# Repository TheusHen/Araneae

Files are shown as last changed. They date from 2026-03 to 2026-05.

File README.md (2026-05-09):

<table align="center">
<tr>
<td>

<h1>Araneae</h1>

</td>
<td>



</td>
</tr>
</table>

<h3 align="center">
Your network should answer to you, not report on you.
</h3>

<p align="center">
  
  
</p>

<p align="center">
  
</p>

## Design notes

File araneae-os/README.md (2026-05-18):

# Araneae OS Starter Kit

Custom OpenWrt image scaffold for a Raspberry Pi Compute Module 4 / Raspberry Pi 4 router appliance with:

- LuCI + HTTPS
- WireGuard VPN generated on first boot
- Mattermost local chat server reachable only from WireGuard
- Docker + Docker Compose
- NVMe/USB/storage packages
- Samba/NFS packages
- collectd monitoring + LuCI statistics
- safe first-boot provisioning scripts

This repo is a starter kit, not a finished commercial firmware. It is designed to get your first Araneae OS image building quickly, then let you evolve it into a full OpenWrt fork later.

---

## Target

Default target profile:

```text
OpenWrt: 24.10.6
Target: bcm27xx/bcm2711
Profile: rpi-4
Package manager: opkg
Hardware: Raspberry Pi CM4 / Raspberry Pi 4 class boards
Rootfs partition: 1024 MB
```

Why 24.10.x? Your current flow uses `opkg`. OpenWrt 25.x/snapshot branches may use different packaging behavior, so keep a separate branch when migrating.

The image uses a larger rootfs partition than OpenWrt's small default because LuCI, Docker, storage packages, and Mattermost support do not fit reliably in the default Raspberry Pi image size.

---

## Build

On Linux or WSL Ubuntu:

```bash
sudo apt update
sudo apt install -y build-essential curl file gawk gettext git libncurses-dev libssl-dev python3 rsync unzip wget zstd

cd araneae-os-starter
./scripts/build-imagebuilder.sh profiles/rpi4-cm4.env
```

The resulting images are copied to:

```text
dist/
```

Flash the appropriate `.img.gz` to SD/eMMC/NVMe using Balena Etcher, Raspberry Pi Imager, or `dd`.

---

## First boot behavior

On first boot, Araneae OS will:

1. Set hostname to `araneae`.
2. Set LAN IP to `192.168.8.1`.
3. Generate WireGuard server keys.
4. Create interface `wg0` at `10.66.66.1/24`.
5. Open UDP `51820` from WAN for WireGuard.
6. Bind Mattermost only to `10.66.66.1:8065`.
7. Block Mattermost access from WAN and LAN.
8. Start Docker and deploy Mattermost + PostgreSQL.

Mattermost Docker images are pulled on first boot. That means the router needs working internet once for the first deployment, unless you later add offline Docker image preloading.

---

## Access

After flashing:

```text
LuCI: https://192.168.8.1
SSH:  ssh root@192.168.8.1
```

Check status:

```sh
/etc/araneae/scripts/status.sh
```

Create a WireGuard peer:

```sh
/etc/araneae/scripts/create-wg-peer.sh phone 10.66.66.2 YOUR_PUBLIC_IP_OR_DDNS
```

Then copy the generated config from:

```text
/etc/araneae/wireguard/peer-phone.conf
```

After connecting to the VPN, open:

```text
http://10.66.66.1:8065
```

---

## Mattermost security model

Mattermost is not exposed on WAN. It is published only on the WireGuard server IP:

```yaml
ports:
  - "10.66.66.1:8065:8065"
```

Firewall rules also block direct LAN/WAN access to port `8065`.

For production, add:

- HTTPS reverse proxy inside the VPN
- pinned Mattermost version updates
- backups for `/srv/araneae/mattermost/volumes`
- external SMTP if you need email invites/password reset
- a private DNS name, for example `chat.araneae.lan`

---

## NVMe behavior

This starter kit is safe by default: it does **not** automatically wipe or format NVMe drives.

If `/dev/nvme0n1p1` already has a filesystem, it tries to mount it at:

```text
/srv
```

If you intentionally want first boot to format `/dev/nvme0n1`, create this marker before building the image:

```text
files/etc/araneae/allow-auto-format-nvme
```

Only do that on blank/test devices.

---

## KSZ9893 / KSZ9896 note

The KSZ switch layer is not fully solved by packages alone. For real hardware you will likely need:

- correct device tree / DT overlay
- DSA configuration, not old `swconfig`, on modern OpenWrt
- the correct Microchip KSZ driver for your kernel/target
- board-specific RGMII/RMII/SPI/I2C reset and interrupt lines

Use Image Builder for the first Araneae OS prototype. Use full OpenWrt buildroot when adding the final KSZ9893 hardware layer.

---

## Repo layout

```text
araneae-os-starter/
├── files/                         # Firmware overlay copied into the image
│   └── etc/
│       ├── araneae/               # Araneae scripts + Mattermost compose
│       ├── init.d/                # araneae-mattermost init service
│       ├── sysctl.d/              # sysctl hardening
│       └── uci-defaults/          # first boot provisioning
├── packages/                      # package lists
├── profiles/                      # target build envs
├── scripts/                       # build scripts
└── docs/                          # notes
```

---

## Next steps for a real Araneae OS

1. Add your CM4 carrier board DTS/DTBO.
2. Confirm KSZ9893 driver path and port naming.
3. Add `luci-app-araneae` for your own dashboard.
4. Add backup/restore for WireGuard peers and Mattermost volumes.
5. Add signed OTA sysupgrade metadata.
6. Add GitHub Actions build pipeline.
7. Split editions: `home`, `travel`, `enterprise`, `dev`.

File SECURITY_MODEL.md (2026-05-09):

# Security model — Araneae

This document describes **assets**, **adversaries**, **trust boundaries**, and **assumptions** for the **Araneae** project, aligned with the principle that your network should answer to you, not report on you, and with the planned technical design (CM4, network, NAS/SSD, LiFePO4 UPS, Rust/C/Assembly, future OpenWrt base).

It is not a substitute for formal analysis for commercial certifications; it guides design, contribution review, and communication with users.

## Security objectives

| Objective | Meaning in Araneae |
|---|---|
| **Confidentiality** | User traffic and data must not be exposed by hidden telemetry, undocumented services, or a default configuration that is “too open.” |
| **Integrity** | Firmware, configuration, and system images must be buildable and verifiable; updates must be understandable to the operator. |
| **Availability** | Internal UPS (LiFePO4, power path, BMS) and sound power practices aim for continuity; the device is still not immune to physical failure or DoS. |

## Primary assets

1. **Data at rest** — content on SSD/NAS (PCIe), possibly user-encrypted (not mandatory for the project, but relevant to threats).
2. **Data in transit** — WAN/LAN, VPN, Tor, proxy; keys and policies defined by the user.
3. **Credentials and policies** — SSH is allowed by philosophy of direct control; that requires **documented hardening** and secure defaults where possible.
4. **Firmware / OS integrity** — OpenWrt or equivalent image, boot chain, possible signatures (future).
5. **Hardware** — CM4, BCM54210PE PHY, KSZ9893 switch, MP1584 converters, UPS chain, USB-C/A, HDMI, **EXT_GPIO** on the 26-pin header.

- **Inside the box:** everything running on the SoC and services chosen by the user is “trusted” only insofar as the **operator** trusts the image they installed and the configuration.
- **Outside the box:** WAN and clients are untrusted by default.

## Adversaries considered

1. **Remote (network)** — exploitation of exposed services, drive-by on the LAN, WAN MITM if the user does not use adequate protections.
2. **Local (internal network)** — compromised LAN devices trying to escalate or reach NAS/services.
3. **Physical, brief access** — USB media insertion, connection to a debug header (SWD), attempts to read storage.
4. **Physical, prolonged possession** — SSD extraction, PCB tampering; mitigation is usually **encryption** + operational policy, not firmware alone.
5. **Supply chain** — components, toolchain, chip firmware blobs (PHY, switch, etc.). The project seeks **maximum openness**, but some elements may remain proprietary in practice; that must be **documented honestly**.

## Privacy and telemetry

- **Product requirement:** **zero undocumented telemetry.** Any diagnostic channel must be **explicit**, **local**, or **opt-in**.
- **Security implication:** no “phone home” reduces surface and metadata leakage, but **does not** remove other vectors (e.g. a misconfigured self-hosted service).

## Hardware — security implications

| Component | Security / trust note |
|---|---|
| **CM4 + eMMC/SD** | Boot vector; protect updates and, if desired, secure boot (future policy to document). |
| **PCIe SSD** | Sensitive data; user encryption recommended for physical threat. |
| **USB-C / USB-A** | Classic attack surface; ESD and mount/automount policy should be conservative by default. |
| **Exposed GPIO / I2C** | Headers improve hackability; they also widen surface if an attacker has physical access. |
| **UPS / I2C (e.g. LTC4015)** | **Local** battery telemetry is desirable for operation; it must not become network exfiltration without consent. |
| **KSZ9893 / MDIO-SPI** | Traffic monitoring is a **feature**; it must be under operator control, not hidden third parties. |

## Software — stack and surface

- **Rust** — services and control (incl. GPIO); reduces some memory-error classes, but logic can still fail.
- **C / Assembly** — low-level integration; careful review; avoid unnecessary `unsafe` in Rust wrapping FFI.
- **OpenWrt (planned)** — defaults, packages, and init must respect Araneae philosophy; contributions that add analytics or undocumented services are **misaligned**.

## What Araneae does not guarantee

- Protection against an **operator** who disables the firewall or exposes insecure services.
- Resistance to **lab-grade physical attacks** without extra measures (mesh, tamper evidence, encryption).
- Security of **third-party applications** (self-hosted — e.g. RustDesk, VPN) beyond what the project documents as integration.

## Relationship to [SECURITY.md](./SECURITY.md)

Vulnerabilities that break the promises above (e.g. hidden telemetry, backdoor, RCE in documented default configuration) should be reported through the security policy. Improvements to this model are welcome via contributions that stay clear and honest about limitations.

## Summary

Araneae combines **verifiable open hardware**, **auditable software**, and **privacy by design**. Effective security depends on **conscious configuration**, **updates**, and — when physical threat matters — **encryption and operational policies** chosen by the user.

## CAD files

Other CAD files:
hardware/Araneae/3d/TLV809K33DBZR.step
hardware/Araneae/3d/USB2514B_M2.step
hardware/Araneae/3d/TMP117AIDRVR.step
hardware/Araneae/3d/RT9742GGJ5.step
hardware/Araneae/3d/LTC4015EUHF.step
hardware/Araneae/3d/MDT320M01001.step
hardware/Araneae/3d/MP1584EN-LF-Z.step
hardware/Araneae/3d/IRLR7843.step
hardware/Araneae/3d/TLV809I50DBZT.step
hardware/Araneae/3d/1048.step
hardware/Araneae/3d/FH12-22S-0.5SH.stp
hardware/Araneae/3d/KSZ9893RNXI.step
hardware/Araneae/3d/NC7SB3157P6X.step
hardware/Araneae/3d/TPS3430WDRCR.step
hardware/Araneae/3d/DF40HC_3.0_-100DS-0.4V_58.step
hardware/Araneae/3d/TPS54331DG4.step
hardware/Araneae/3d/TPS22946YZPR.step
hardware/Araneae/3d/BQ24610RGET.step
hardware/Araneae/3d/ISL94202IRTZ.step

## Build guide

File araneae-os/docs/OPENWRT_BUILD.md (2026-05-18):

# Full OpenWrt buildroot path

Use Image Builder for package + overlay images.

Use full OpenWrt buildroot when you need:

- kernel config changes
- custom DTS/DTBO for your CM4 carrier board
- KSZ9893/KSZ9896 switch integration
- custom LuCI app package
- Araneae branding in base-files
- signed package feeds

Suggested flow:

```bash
git clone https://git.openwrt.org/openwrt/openwrt.git
cd openwrt
git checkout v24.10.6
./scripts/feeds update -a
./scripts/feeds install -a
make menuconfig
```

Then copy `files/` from this starter kit into the OpenWrt tree root and add your board patches.

Build:

```bash
make -j$(nproc)
```

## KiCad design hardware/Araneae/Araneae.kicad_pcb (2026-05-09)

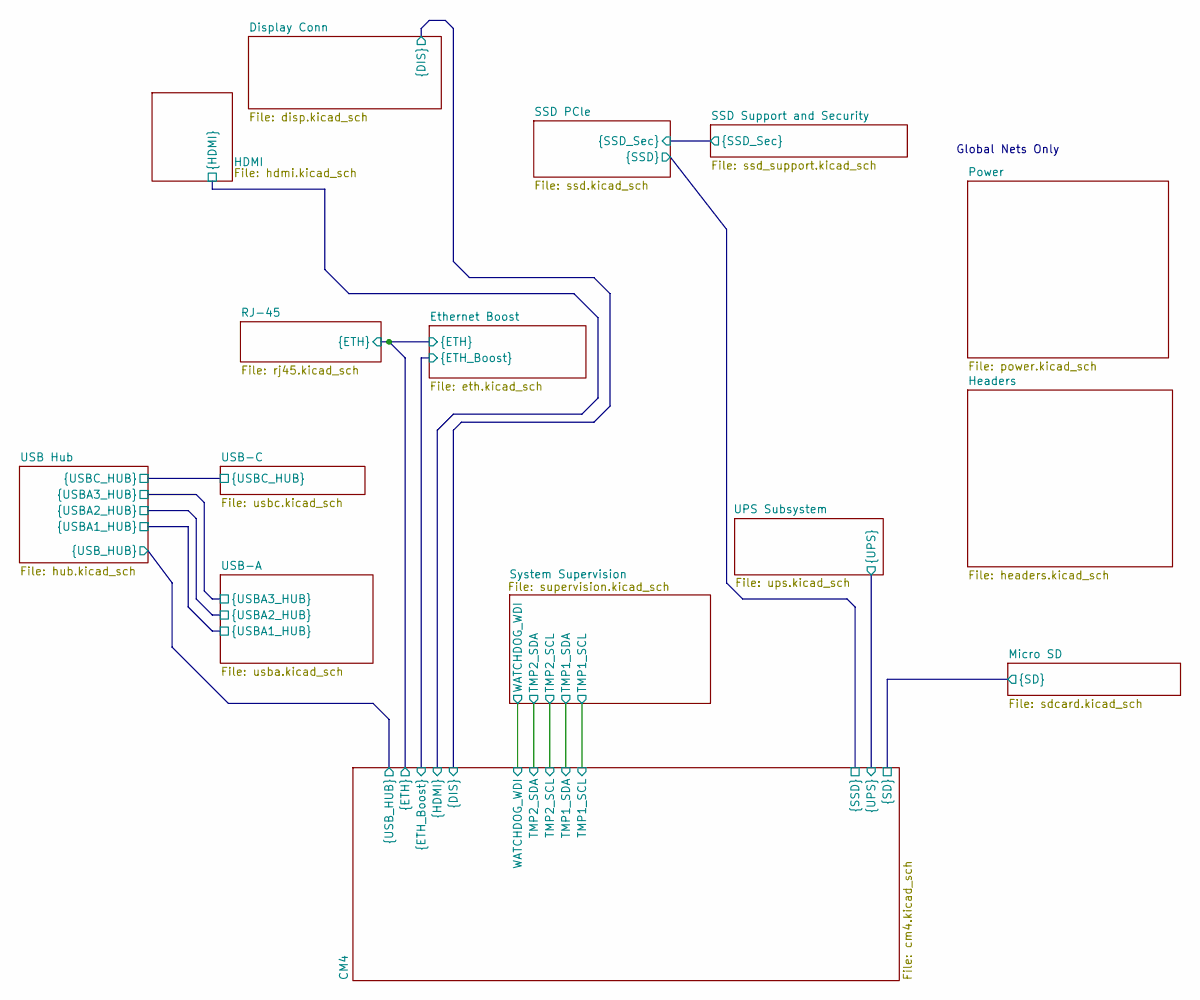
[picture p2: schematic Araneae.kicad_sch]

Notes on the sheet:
Global Nets Only

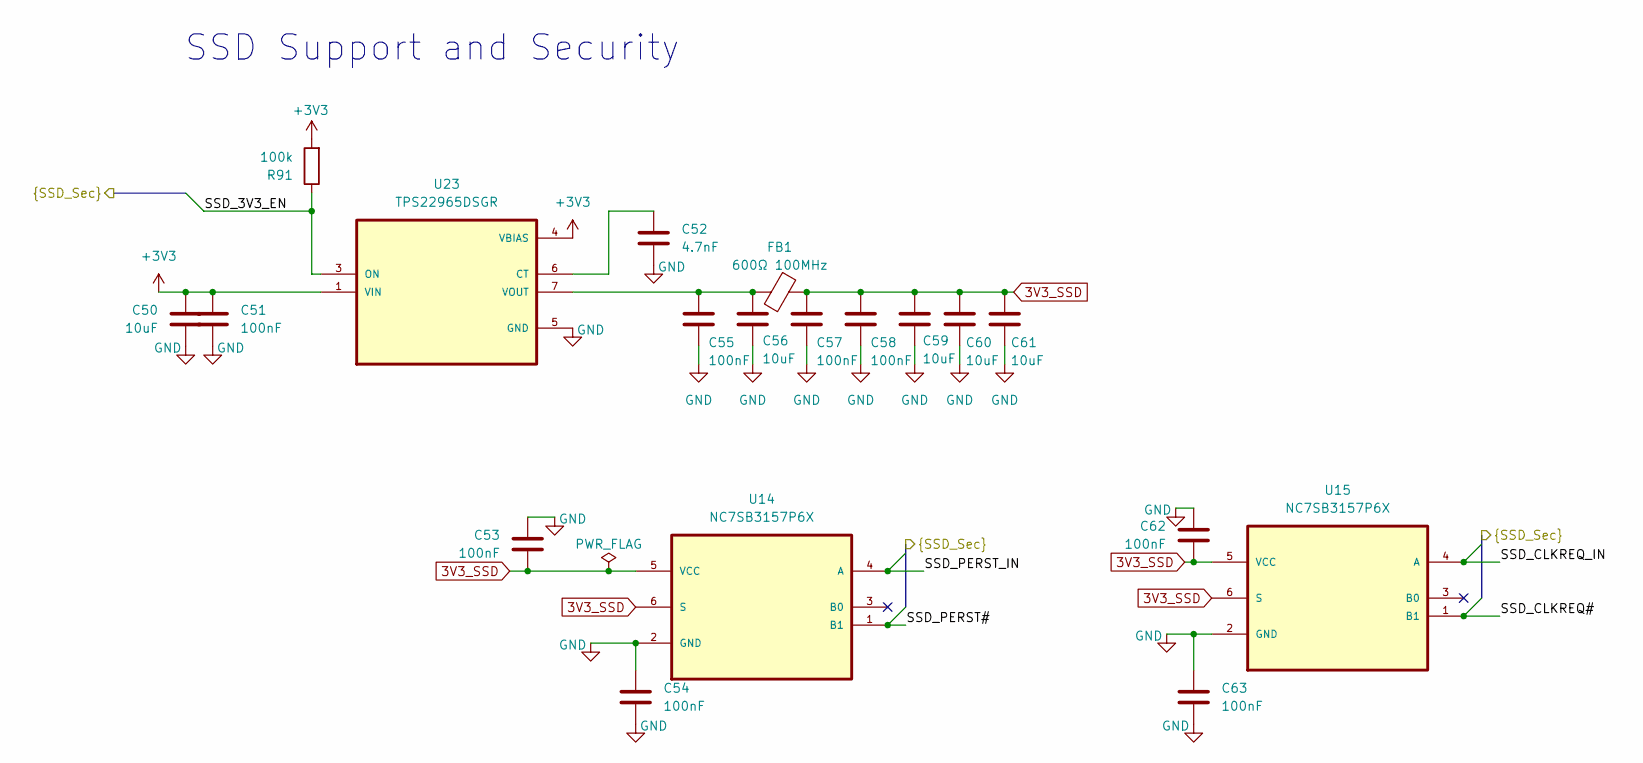
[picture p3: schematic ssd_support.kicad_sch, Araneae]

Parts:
C50, C56, C59: 10uF; C_0603_1608Metric
C51, C57, C62: 100nF; C_0805_2012Metric
C52: 4.7nF; C_0603_1608Metric
C53, C54, C55, C58, C63: 100nF; C_0603_1608Metric
C60, C61: 10uF; C_0805_2012Metric
FB1: 600Ω 100MHz; L_0805_2012Metric
R91: 100k; R_0603_1608Metric
U14, U15: NC7SB3157P6X; SOT65P210X110-6N; MPN NC7SB3157P6X
U23: TPS22965DSGR; SON50P200X200X80-9N

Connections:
3V3_SSD: C53.2, C57.1, C58.1, C59.1, C60.1, C61.1, C62.2, FB1.1, U14.5 (VCC), U14.6 (S), U15.5 (VCC), U15.6 (S); also elsewhere on the board
+3V3: C50.1, C51.1, R91.2, U23.1 (VIN), U23.2 (VIN), U23.4 (VBIAS); also elsewhere on the board
/SSD PCle/SSD_3V3_EN: R91.1, U23.3 (ON)
/SSD PCle/SSD_CLKREQ#: U15.1 (B1); also elsewhere on the board
/SSD PCle/SSD_CLKREQ_IN: U15.4 (A)
/SSD PCle/SSD_PERST#: U14.1 (B1); also elsewhere on the board
/SSD PCle/SSD_PERST_IN: U14.4 (A)
GND: C50.2, C51.2, C52.2, C53.1, C54.1, C54.2, C55.2, C56.2, C57.2, C58.2, C59.2, C60.2, C61.2, C62.1, C63.1, C63.2, U14.2 (GND), U15.2 (GND), U23.5 (GND), U23.9 (GND), U23.9_1 (GND), U23.9_2 (GND); also elsewhere on the board
unnamed: C55.1, C56.1, FB1.2, U23.7 (VOUT), U23.8 (VOUT)
unnamed: C52.1, U23.6 (CT)

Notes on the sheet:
SSD Support and Security

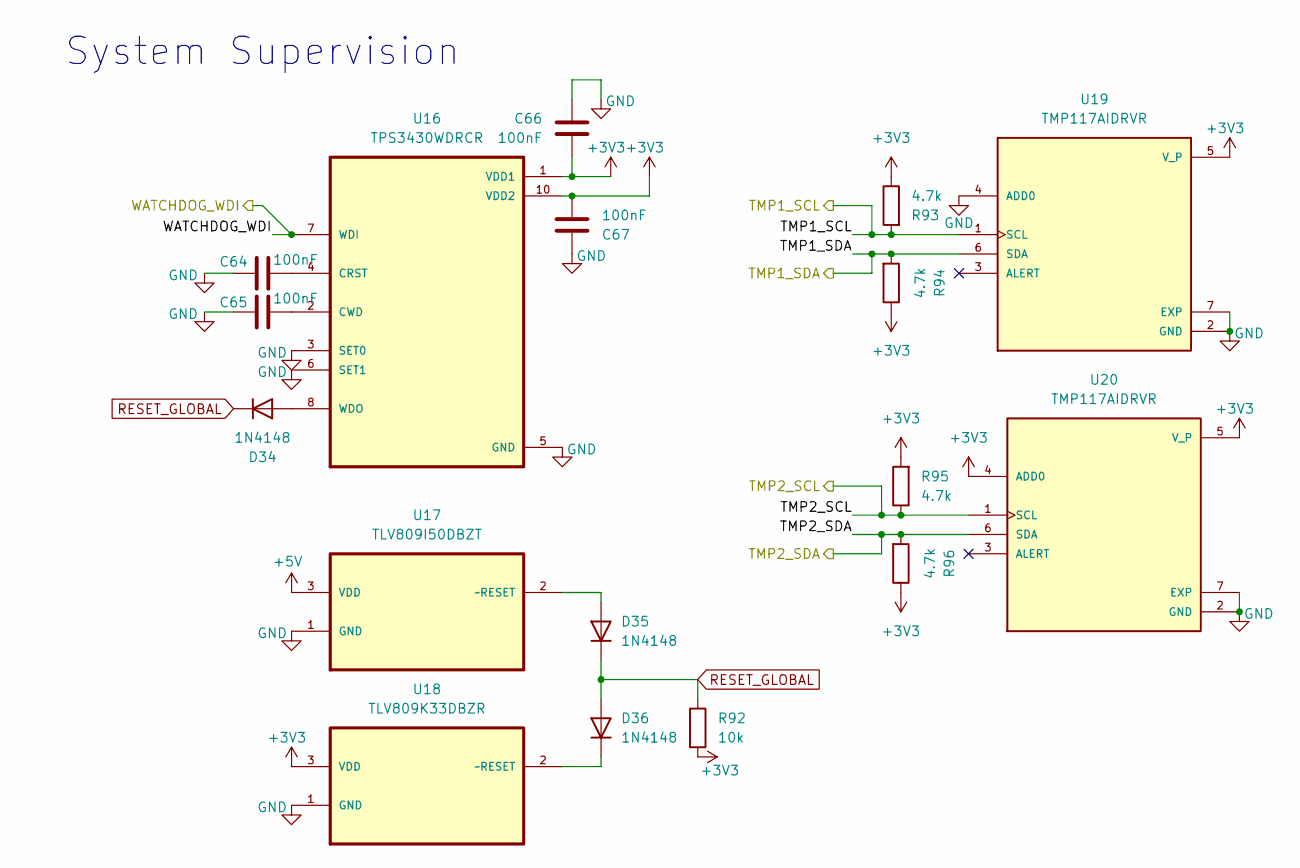
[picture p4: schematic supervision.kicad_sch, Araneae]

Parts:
C64, C65, C66, C67: 100nF; C_0603_1608Metric
D34, D35, D36: 1N4148; D_DO-35_SOD27_P7.62mm_Horizontal
R92: 10k; R_0603_1608Metric
R93, R94, R95, R96: 4.7k; R_0603_1608Metric
U16: TPS3430WDRCR; VREG_V62_16624-01YE
U17: TLV809I50DBZT; SOT95P280X145-3N; MPN TLV809I50DBZT
U18: TLV809K33DBZR; SOT95P280X145-3N; MPN TLV809K33DBZR
U19, U20: TMP117AIDRVR; SON65P200X200X80-7N; PARTREV B

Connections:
+3V3: C66.1, C67.1, R92.2, R93.1, R94.1, R95.2, R96.1, U16.1 (VDD1), U16.10 (VDD2), U18.3 (VDD), U19.5 (V_P), U20.4 (ADD0), U20.5 (V_P); also elsewhere on the board
+5V: U17.3 (VDD); also elsewhere on the board
/CM4/WATCHDOG_WDI: U16.7 (WDI); also elsewhere on the board
EXT_I2C_SCL: R93.2, R95.1, U19.1 (SCL), U20.1 (SCL); also elsewhere on the board
EXT_I2C_SDA: R94.2, R96.2, U19.6 (SDA), U20.6 (SDA); also elsewhere on the board
GND: C64.2, C65.2, C66.2, C67.2, U16.3 (SET0), U16.5 (GND), U16.6 (SET1), U17.1 (GND), U18.1 (GND), U19.2 (GND), U19.4 (ADD0), U19.7 (EXP), U20.2 (GND), U20.7 (EXP); also elsewhere on the board
unnamed: D34.2 (A), U16.8 (WDO)
unnamed: D35.2 (A), U17.2 (~RESET)
unnamed: D36.1 (K), U18.2 (~RESET)
unnamed: C64.1, U16.4 (CRST)
unnamed: C65.1, U16.2 (CWD)
RESET_GLOBAL: D34.1 (K), D35.1 (K), D36.2 (A), R92.1; also elsewhere on the board

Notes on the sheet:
System Supervision

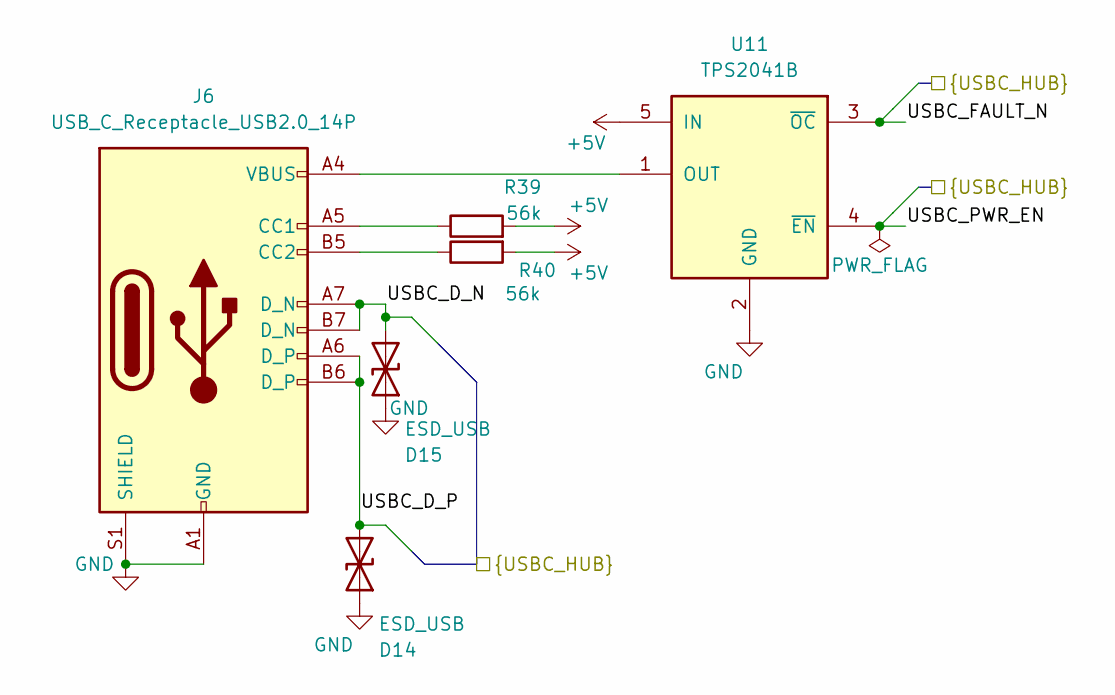
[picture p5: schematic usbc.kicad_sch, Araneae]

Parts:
D14, D15: ESD_USB; D_SOD-323
J6: USB_C_Receptacle_USB2.0_14P; USB_C_Receptacle_HRO_TYPE-C-31-M-12
R39, R40: 56k; R_0603_1608Metric
U11: TPS2041B; SOT-23-5

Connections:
+5V: R39.2, R40.2, U11.5 (IN); also elsewhere on the board
/USB Hub/USBC_D_N: D15.2 (A2), J6.A7 (D_N), J6.B7 (D_N); also elsewhere on the board
/USB Hub/USBC_D_P: D14.2 (A2), J6.A6 (D_P), J6.B6 (D_P); also elsewhere on the board
/USB Hub/USBC_FAULT_N: U11.3 (~OC); also elsewhere on the board
/USB Hub/USBC_PWR_EN: U11.4 (~EN); also elsewhere on the board
GND: D14.1 (A1), D15.1 (A1), J6.A1 (GND), J6.A12 (GND), J6.B1 (GND), J6.B12 (GND), J6.S1 (SHIELD), U11.2 (GND); also elsewhere on the board
unnamed: J6.A5 (CC1), R39.1
unnamed: J6.B5 (CC2), R40.1
unnamed: J6.A4 (VBUS), J6.A9 (VBUS), J6.B4 (VBUS), J6.B9 (VBUS), U11.1 (OUT)

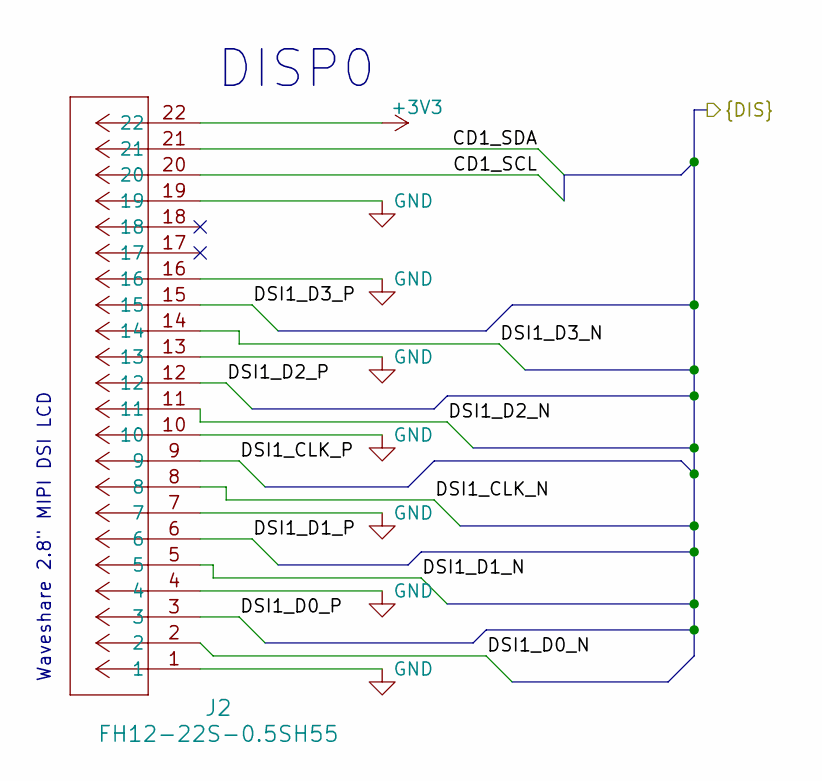
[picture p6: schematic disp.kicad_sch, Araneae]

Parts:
J2: FH12-22S-0.5SH55; CONN_FH12-22S-0.5SH55_HIR

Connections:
+3V3: J2.22; also elsewhere on the board
/CM4/CD1_SCL: J2.20; also elsewhere on the board
/CM4/CD1_SDA: J2.21; also elsewhere on the board
/CM4/DSI1_CLK_N: J2.8; also elsewhere on the board
/CM4/DSI1_CLK_P: J2.9; also elsewhere on the board
/CM4/DSI1_D0_N: J2.2; also elsewhere on the board
/CM4/DSI1_D0_P: J2.3; also elsewhere on the board
/CM4/DSI1_D1_N: J2.5; also elsewhere on the board
/CM4/DSI1_D1_P: J2.6; also elsewhere on the board
/CM4/DSI1_D2_N: J2.11; also elsewhere on the board
/CM4/DSI1_D2_P: J2.12; also elsewhere on the board
/CM4/DSI1_D3_N: J2.14; also elsewhere on the board
/CM4/DSI1_D3_P: J2.15; also elsewhere on the board
GND: J2.1, J2.4, J2.7, J2.10, J2.13, J2.16, J2.19; also elsewhere on the board

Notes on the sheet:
DISP0
Waveshare 2.8" MIPI DSI LCD

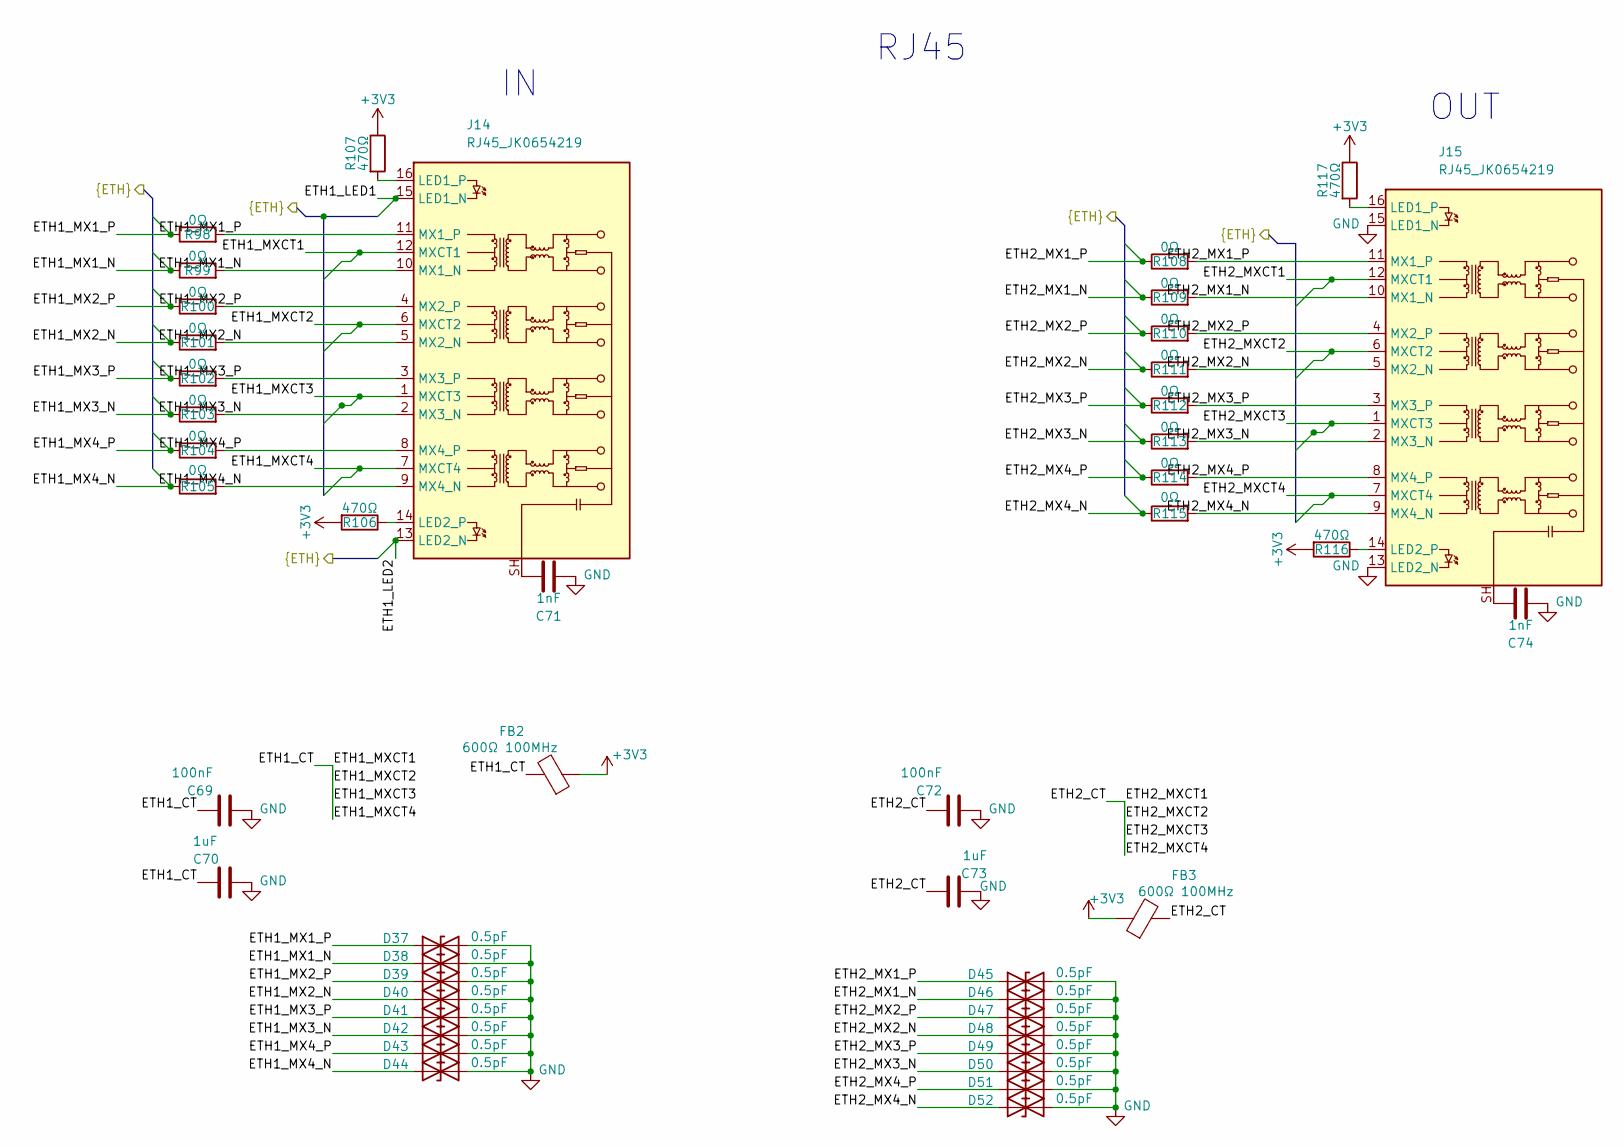
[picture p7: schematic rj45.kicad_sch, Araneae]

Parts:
C69: 100nF; C_0805_2012Metric
C70, C73: 1uF; C_0603_1608Metric
C71, C74: 1nF; C_0603_1608Metric
C72: 100nF; C_0603_1608Metric
D37, D38, D39, D40, D41, D42, D43, D44, D45, D46, D47, D48, D49, D50, D51, D52: 0.5pF; D_SOD-523
FB2, FB3: 600Ω 100MHz; L_0805_2012Metric
J14, J15: RJ45_JK0654219; RJ45_Pulse_JK0654219NL_Horizontal
R98, R99, R100, R101, R102, R103, R104, R105, R108, R109, R110, R111, R112, R113, R114, R115: 0Ω; R_0603_1608Metric
R106, R107, R116, R117: 470Ω; R_0603_1608Metric

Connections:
+3V3: FB2.1, FB3.1, R106.2, R107.1, R116.2, R117.1; also elsewhere on the board
/CM4/ETH1_LED1: J14.15 (LED1_N); also elsewhere on the board
/CM4/ETH1_LED2: J14.13 (LED2_N); also elsewhere on the board
/CM4/ETH1_MX1_N: D38.1 (A1), J14.10 (MX1_N), R99.1, R99.2; also elsewhere on the board
/CM4/ETH1_MX1_P: D37.1 (A1), J14.11 (MX1_P), R98.1, R98.2; also elsewhere on the board
/CM4/ETH1_MX2_N: D40.1 (A1), J14.5 (MX2_N), R101.1, R101.2; also elsewhere on the board
/CM4/ETH1_MX2_P: D39.1 (A1), J14.4 (MX2_P), R100.1, R100.2; also elsewhere on the board
/CM4/ETH1_MX3_N: D42.1 (A1), J14.2 (MX3_N), R103.1, R103.2; also elsewhere on the board
/CM4/ETH1_MX3_P: D41.1 (A1), J14.3 (MX3_P), R102.1, R102.2; also elsewhere on the board
/CM4/ETH1_MX4_N: D44.1 (A1), J14.9 (MX4_N), R105.1, R105.2; also elsewhere on the board
/CM4/ETH1_MX4_P: D43.1 (A1), J14.8 (MX4_P), R104.1, R104.2; also elsewhere on the board
/CM4/ETH1_MXCT4: C69.1, C70.2, FB2.2, J14.1 (MXCT3), J14.6 (MXCT2), J14.7 (MXCT4), J14.12 (MXCT1)
/CM4/ETH2_MX1_N: D46.1 (A1), J15.10 (MX1_N), R109.1, R109.2; also elsewhere on the board
/CM4/ETH2_MX1_P: D45.1 (A1), J15.11 (MX1_P), R108.1, R108.2; also elsewhere on the board
/CM4/ETH2_MX2_N: D48.1 (A1), J15.5 (MX2_N), R111.1, R111.2; also elsewhere on the board
/CM4/ETH2_MX2_P: D47.1 (A1), J15.4 (MX2_P), R110.1, R110.2; also elsewhere on the board
/CM4/ETH2_MX3_N: D50.1 (A1), J15.2 (MX3_N), R113.1, R113.2; also elsewhere on the board
/CM4/ETH2_MX3_P: D49.1 (A1), J15.3 (MX3_P), R112.1, R112.2; also elsewhere on the board
/CM4/ETH2_MX4_N: D52.1 (A1), J15.9 (MX4_N), R115.1, R115.2; also elsewhere on the board
/CM4/ETH2_MX4_P: D51.1 (A1), J15.8 (MX4_P), R114.1, R114.2; also elsewhere on the board
/CM4/ETH2_MXCT4: C72.1, C73.1, FB3.2, J15.1 (MXCT3), J15.6 (MXCT2), J15.7 (MXCT4), J15.12 (MXCT1)
GND: C69.2, C70.1, C71.2, C72.2, C73.2, C74.2, D37.2 (A2), D38.2 (A2), D39.2 (A2), D40.2 (A2), D41.2 (A2), D42.2 (A2), D43.2 (A2), D44.2 (A2), D45.2 (A2), D46.2 (A2), D47.2 (A2), D48.2 (A2), D49.2 (A2), D50.2 (A2), D51.2 (A2), D52.2 (A2), J15.13 (LED2_N), J15.15 (LED1_N); also elsewhere on the board
unnamed: C71.1, J14.SH
unnamed: C74.1, J15.SH
unnamed: J14.16 (LED1_P), R107.2
unnamed: J14.14 (LED2_P), R106.1
unnamed: J15.16 (LED1_P), R117.2
unnamed: J15.14 (LED2_P), R116.1

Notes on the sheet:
OUT
RJ45

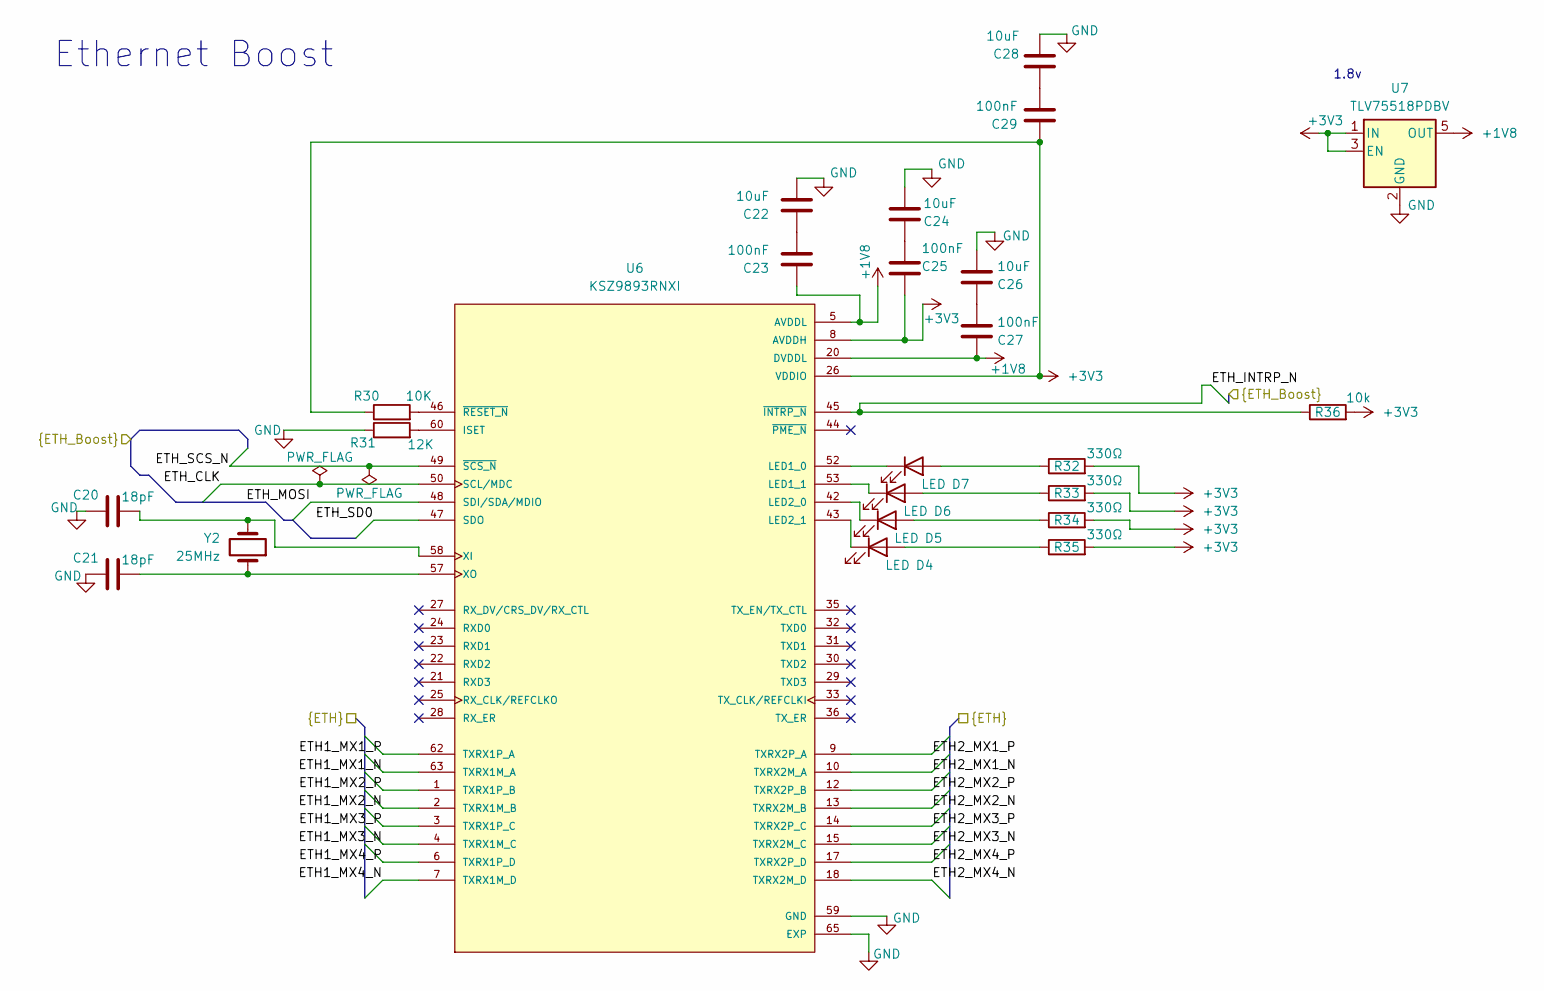
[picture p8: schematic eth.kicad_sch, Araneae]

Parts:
C20, C21: 18pF; C_0603_1608Metric
C22, C24, C26, C28: 10uF; C_0805_2012Metric
C23, C25, C27, C29: 100nF; C_0603_1608Metric
D4, D5, D6, D7: LED; LED_0805_2012Metric
R30: 10K; R_0603_1608Metric
R31: 12K; R_0603_1608Metric
R32, R33, R34, R35: 330Ω; R_0603_1608Metric
R36: 10k; R_0603_1608Metric
U6: KSZ9893RNXI; QFN40P800X800X90-65N; PARTREV C
U7: TLV75518PDBV; SOT-23-5
Y2: 25MHz; Crystal_SMD_3225-4Pin_3.2x2.5mm

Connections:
+1V8: C23.1, C27.1, U6.5 (AVDDL), U6.11 (AVDDL), U6.16 (AVDDL), U6.20 (DVDDL), U6.34 (DVDDL), U6.37 (DVDDL), U6.41 (DVDDL), U6.51 (DVDDL), U6.55 (DVDDL), U6.56 (AVDDL), U6.64 (AVDDL), U7.5 (OUT); also elsewhere on the board
+3V3: C25.1, C29.1, R30.1, R32.2, R33.2, R34.2, R35.2, R36.2, U6.8 (AVDDH), U6.19 (AVDDH), U6.26 (VDDIO), U6.38 (VDDIO), U6.54 (VDDIO), U6.61 (AVDDH), U7.1 (IN), U7.3 (EN); also elsewhere on the board
/CM4/ETH1_MX1_N: U6.63 (TXRX1M_A); also elsewhere on the board
/CM4/ETH1_MX1_P: U6.62 (TXRX1P_A); also elsewhere on the board
/CM4/ETH1_MX2_N: U6.2 (TXRX1M_B); also elsewhere on the board
/CM4/ETH1_MX2_P: U6.1 (TXRX1P_B); also elsewhere on the board
/CM4/ETH1_MX3_N: U6.4 (TXRX1M_C); also elsewhere on the board
/CM4/ETH1_MX3_P: U6.3 (TXRX1P_C); also elsewhere on the board
/CM4/ETH1_MX4_N: U6.7 (TXRX1M_D); also elsewhere on the board
/CM4/ETH1_MX4_P: U6.6 (TXRX1P_D); also elsewhere on the board
/CM4/ETH2_MX1_N: U6.10 (TXRX2M_A); also elsewhere on the board
/CM4/ETH2_MX1_P: U6.9 (TXRX2P_A); also elsewhere on the board
/CM4/ETH2_MX2_N: U6.13 (TXRX2M_B); also elsewhere on the board
/CM4/ETH2_MX2_P: U6.12 (TXRX2P_B); also elsewhere on the board
/CM4/ETH2_MX3_N: U6.15 (TXRX2M_C); also elsewhere on the board
/CM4/ETH2_MX3_P: U6.14 (TXRX2P_C); also elsewhere on the board
/CM4/ETH2_MX4_N: U6.18 (TXRX2M_D); also elsewhere on the board
/CM4/ETH2_MX4_P: U6.17 (TXRX2P_D); also elsewhere on the board
/CM4/ETH_INTRP_N: R36.1, U6.45 (~INTRP_N); also elsewhere on the board
/CM4/ETH_SCS_N: U6.49 (~SCS_N); also elsewhere on the board
EXT_SPI_MISO: U6.47 (SDO); also elsewhere on the board
EXT_SPI_MOSI: U6.48 (SDI/SDA/MDIO); also elsewhere on the board
EXT_SPI_SCLK: U6.50 (SCL/MDC); also elsewhere on the board
GND: C20.1, C21.1, C22.2, C24.2, C26.2, C28.2, R31.1, U6.59 (GND), U6.65 (EXP), U6.65_1 (EXP), U6.65_2 (EXP), U6.65_3 (EXP), U6.65_4 (EXP), U6.65_5 (EXP), U6.65_6 (EXP), U6.65_7 (EXP), U6.65_8 (EXP), U6.65_9 (EXP), U6.65_10 (EXP), U6.65_11 (EXP), U6.65_12 (EXP), U6.65_13 (EXP), U6.65_14 (EXP), U6.65_15 (EXP), U6.65_16 (EXP), U6.65_17 (EXP), U6.65_18 (EXP), U6.65_19 (EXP), U6.65_20 (EXP), U6.65_21 (EXP), U6.65_22 (EXP), U6.65_23 (EXP), U6.65_24 (EXP), U6.65_25 (EXP), U6.65_26 (EXP), U6.65_27 (EXP), U6.65_28 (EXP), U6.65_29 (EXP), U6.65_30 (EXP), U6.65_31 (EXP), U6.65_32 (EXP), U6.65_33 (EXP), U6.65_34 (EXP), U6.65_35 (EXP), U6.65_36 (EXP), U7.2 (GND); also elsewhere on the board
unnamed: C22.1, C23.2
unnamed: C24.1, C25.2
unnamed: C26.1, C27.2
unnamed: C28.1, C29.2
unnamed: D4.2 (A), R35.1
unnamed: D4.1 (K), U6.43 (LED2_1)
unnamed: D5.2 (A), R34.1
unnamed: D5.1 (K), U6.42 (LED2_0)
unnamed: D6.2 (A), R33.1
unnamed: D6.1 (K), U6.53 (LED1_1)
unnamed: D7.2 (A), R32.1
unnamed: D7.1 (K), U6.52 (LED1_0)
unnamed: R31.2, U6.60 (ISET)
unnamed: C20.2, U6.58 (XI), Y2.2
unnamed: C21.2, U6.57 (XO), Y2.1
unnamed: R30.2, U6.46 (~RESET_N)

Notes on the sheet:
Ethernet Boost
1.8v

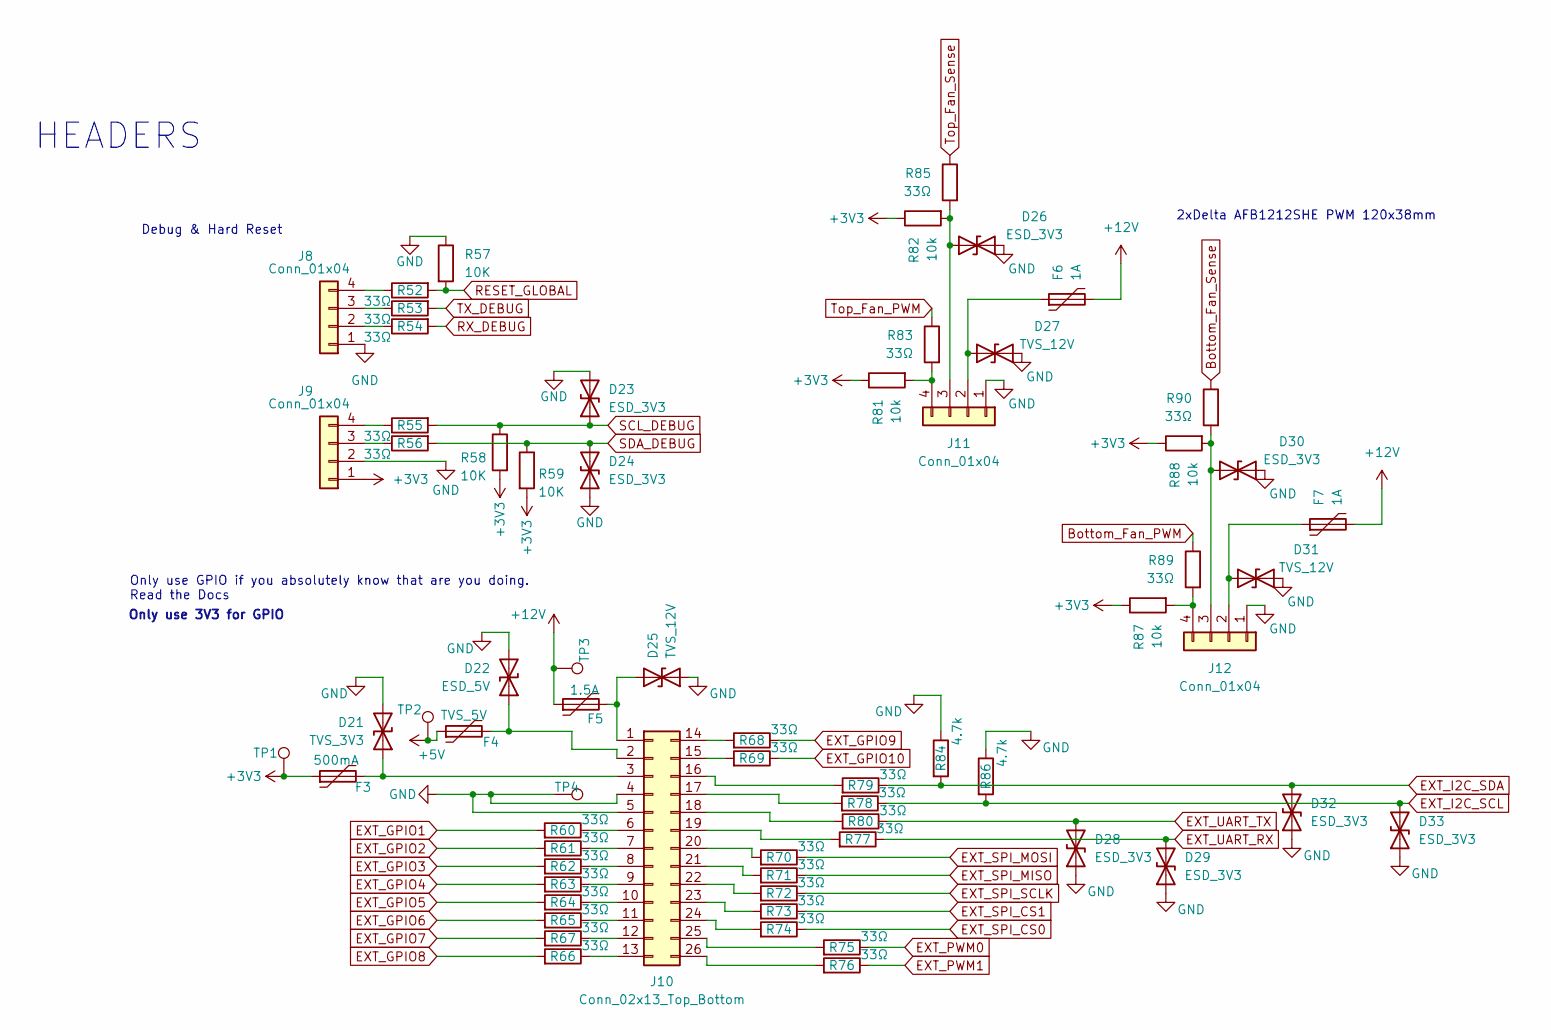
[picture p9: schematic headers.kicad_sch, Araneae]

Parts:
D21: TVS_3V3; D_SOD-323
D22: ESD_5V; D_SOD-323
D23, D24, D26, D28, D29, D30, D32, D33: ESD_3V3; D_SOD-323
D25, D27, D31: TVS_12V; D_SMF
F3: 500mA; Fuse_1206_3216Metric
F4: TVS_5V; Fuse_1206_3216Metric
F5: 1.5A; Fuse_1812_4532Metric
F6, F7: 1A; Fuse_1812_4532Metric
J8, J9, J11, J12: Conn_01x04; PinHeader_1x04_P2.54mm_Vertical
J10: Conn_02x13_Top_Bottom; IDC-Header_2x13_P2.54mm_Horizontal
R52, R53, R54, R55, R56, R60, R61, R62, R63, R64, R65, R66, R67, R68, R69, R70, R71, R72, R73, R74, R75, R76, R77, R78, R79, R80, R83, R85, R89, R90: 33Ω; R_0603_1608Metric
R57, R58, R59: 10K; R_0603_1608Metric
R81, R82, R87, R88: 10k; R_0603_1608Metric
R84, R86: 4.7k; R_0603_1608Metric
TP1, TP2, TP3, TP4: TestPoint_Pad_D1.5mm

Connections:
+3V3: F3.1, J9.1, R58.2, R59.2, R81.1, R82.1, R87.1, R88.1, TP1.1 (1_1); also elsewhere on the board
+5V: F4.1, TP2.1 (1_1); also elsewhere on the board
+12V: F5.1, F6.2, F7.2, TP3.1 (1_1); also elsewhere on the board
Bottom_Fan_PWM: R89.1; also elsewhere on the board
Bottom_Fan_Sense: R90.1; also elsewhere on the board
EXT_GPIO1: R60.2; also elsewhere on the board
EXT_GPIO2: R61.2; also elsewhere on the board
EXT_GPIO3: R62.2; also elsewhere on the board
EXT_GPIO4: R63.2; also elsewhere on the board
EXT_GPIO5: R64.2; also elsewhere on the board
EXT_GPIO6: R65.2; also elsewhere on the board
EXT_GPIO7: R67.2; also elsewhere on the board
EXT_GPIO8: R66.2; also elsewhere on the board
EXT_GPIO9: R68.1; also elsewhere on the board
EXT_GPIO10: R69.1; also elsewhere on the board
EXT_I2C_SCL: D33.2 (A2), R78.1, R86.2; also elsewhere on the board
EXT_I2C_SDA: D32.2 (A2), R79.1, R84.2; also elsewhere on the board
EXT_PWM0: R75.1; also elsewhere on the board
EXT_PWM1: R76.1; also elsewhere on the board
EXT_SPI_CS0: R74.1; also elsewhere on the board
EXT_SPI_CS1: R73.1; also elsewhere on the board
EXT_SPI_MISO: R71.1; also elsewhere on the board
EXT_SPI_MOSI: R70.1; also elsewhere on the board
EXT_SPI_SCLK: R72.1; also elsewhere on the board
EXT_UART_RX: D29.2 (A2), R77.1; also elsewhere on the board
EXT_UART_TX: D28.2 (A2), R80.1; also elsewhere on the board
GND: D21.2 (A2), D22.2 (A2), D23.2 (A2), D24.1 (A1), D25.1 (A1), D26.1 (A1), D27.1 (A1), D28.1 (A1), D29.1 (A1), D30.1 (A1), D31.1 (A1), D32.1 (A1), D33.1 (A1), J8.1, J9.2, J10.4, J10.5, J11.1, J12.1, R57.1, R84.1, R86.1, TP4.1 (1_1); also elsewhere on the board
unnamed: D21.1 (A1), F3.2, J10.3
unnamed: D22.1 (A1), F4.2, J10.2
unnamed: D25.2 (A2), F5.2, J10.1
unnamed: D26.2 (A2), J11.3, R82.2, R85.2
unnamed: D27.2 (A2), F6.1, J11.2
unnamed: D30.2 (A2), J12.3, R88.2, R90.2
unnamed: D31.2 (A2), F7.1, J12.2
unnamed: J8.2, R54.1
unnamed: J8.3, R53.1
unnamed: J8.4, R52.1
unnamed: J9.3, R56.1
unnamed: J9.4, R55.1
unnamed: J10.6, R60.1
unnamed: J10.7, R61.1
unnamed: J10.8, R62.1
unnamed: J10.9, R63.1
unnamed: J10.10, R64.1
unnamed: J10.11, R65.1
unnamed: J10.12, R67.1
unnamed: J10.13, R66.1
unnamed: J10.14, R68.2
unnamed: J10.15, R69.2
unnamed: J10.16, R79.2
unnamed: J10.17, R78.2
unnamed: J10.18, R80.2
unnamed: J10.19, R77.2
unnamed: J10.20, R70.2
unnamed: J10.21, R71.2
unnamed: J10.22, R72.2
unnamed: J10.23, R73.2
unnamed: J10.24, R74.2
unnamed: J10.25, R75.2
unnamed: J10.26, R76.2
unnamed: J11.4, R81.2, R83.2
unnamed: J12.4, R87.2, R89.2
RESET_GLOBAL: R52.2, R57.2; also elsewhere on the board
RX_DEBUG: R54.2; also elsewhere on the board
SCL_DEBUG: D23.1 (A1), R55.2, R58.1; also elsewhere on the board
SDA_DEBUG: D24.2 (A2), R56.2, R59.1; also elsewhere on the board
TX_DEBUG: R53.2; also elsewhere on the board
Top_Fan_PWM: R83.1; also elsewhere on the board
Top_Fan_Sense: R85.1; also elsewhere on the board

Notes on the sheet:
Only use GPIO if you absolutely know that are you doing. Read the Docs
HEADERS
Debug & Hard Reset
2xDelta AFB1212SHE PWM 120x38mm
Only use 3V3 for GPIO

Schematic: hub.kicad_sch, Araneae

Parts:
C75, C76: 18pF; C_0603_1608Metric
C77, C78, C79, C80, C81, C82, C83: 100nF; C_0603_1608Metric
C84: 1nF; C_0603_1608Metric
R118: 10k; R_0603_1608Metric
R119: 12k; R_0603_1608Metric
TP5: SUSP_IND; TestPoint_Pad_D1.5mm
U22: USB2514B_M2; 36-SQFN-EXPOSED-PAD
Y3: 24MHz; Crystal_SMD_3225-4Pin_3.2x2.5mm

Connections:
+3V3: C77.2, C78.2, C79.2, C80.2, C81.2, C82.2, R118.1, U22.5 (VDDA33-1), U22.10 (VDDA33-2), U22.15 (VDD33IO), U22.23 (VDD33REG), U22.29 (VDDA33-3), U22.36 (VDDPLLREF); also elsewhere on the board
+5V: U22.27 (VBUS_DET); also elsewhere on the board
/CM4/CM4_USB_D_N: U22.30 (DM-UP); also elsewhere on the board
/CM4/CM4_USB_D_P: U22.31 (DP-UP); also elsewhere on the board
/CM4/USB_HUB_RESET_N: R118.2, U22.26 (~RESET); also elsewhere on the board
/USB Hub/USBA1_D_N: U22.1 (DM1); also elsewhere on the board
/USB Hub/USBA1_D_P: U22.2 (DP1); also elsewhere on the board
/USB Hub/USBA1_FAULT_N: U22.13 (OCS1); also elsewhere on the board
/USB Hub/USBA1_PWR_EN: U22.12 (PRTPWR1); also elsewhere on the board
/USB Hub/USBA2_D_N: U22.3 (DM2); also elsewhere on the board
/USB Hub/USBA2_D_P: U22.4 (DP2); also elsewhere on the board
/USB Hub/USBA2_FAULT_N: U22.17 (OCS2); also elsewhere on the board
/USB Hub/USBA2_PWR_EN: U22.16 (PRTPWR2); also elsewhere on the board
/USB Hub/USBA3_D_N: U22.6 (DM3); also elsewhere on the board
/USB Hub/USBA3_D_P: U22.7 (DP3); also elsewhere on the board
/USB Hub/USBA3_FAULT_N: U22.19 (OCS3); also elsewhere on the board
/USB Hub/USBA3_PWR_EN: U22.18 (PRTPWR3); also elsewhere on the board
/USB Hub/USBC_D_N: U22.8 (DM4); also elsewhere on the board
/USB Hub/USBC_D_P: U22.9 (DP4); also elsewhere on the board
/USB Hub/USBC_FAULT_N: U22.21 (OCS4); also elsewhere on the board
/USB Hub/USBC_PWR_EN: U22.20 (PRTPWR4); also elsewhere on the board
GND: C75.1, C76.1, C77.1, C78.1, C79.1, C80.1, C81.1, C82.1, C83.1, C84.1, R119.1, U22.11 (TEST), U22.22 (SMBDATA), U22.24 (SMBCLK), U22.25 (CFG_SEL1), U22.37 (VSS); also elsewhere on the board
unnamed: C84.2, U22.14 (CRFILT)
unnamed: C83.2, U22.34 (PLLFILT)
unnamed: R119.2, U22.35 (RBIAS)
unnamed: TP5.1 (1_1), U22.28 (SUSP_IND)
unnamed: C75.2, U22.32 (XTAL1), Y3.1
unnamed: C76.2, U22.33 (XTAL2), Y3.2

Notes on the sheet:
USB Hub

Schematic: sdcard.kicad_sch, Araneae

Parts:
C68: 10uF; C_0603_1608Metric
J13: Micro_SD_Card; microSD_HC_Hirose_DM3D-SF
R97: 12k; R_0603_1608Metric
U21: RT9742GGJ5; TSOT-23-5

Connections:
+3V3: R97.1, U21.P$5 (IN); also elsewhere on the board
/CM4/SD_CLK: J13.5 (CLK); also elsewhere on the board
/CM4/SD_DAT0: J13.7 (DAT0); also elsewhere on the board
/CM4/SD_DAT1: J13.8 (DAT1); also elsewhere on the board
/CM4/SD_DAT2: J13.1 (DAT2); also elsewhere on the board
/CM4/SD_DAT3: J13.2 (DAT3/CD); also elsewhere on the board
/CM4/SD_PWR: C68.1, J13.3 (CMD), J13.4 (VDD), U21.P$1 (OUT); also elsewhere on the board
/CM4/SD_PWR_ON: R97.2, U21.P$4 (EN); also elsewhere on the board
GND: C68.2, J13.6 (VSS), J13.9 (SHIELD), U21.P$2 (GND); also elsewhere on the board

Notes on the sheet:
MICRO SD

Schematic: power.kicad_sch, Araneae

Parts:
C32: 10µF; C_0805_2012Metric
C33, C35: 100nF; C_0805_2012Metric
C34: 10µF; C_0603_1608Metric
C36: 150pF; C_0603_1608Metric
C37: 220pF; C_0603_1608Metric
C38, C39, C45, C46: 100nF; C_0603_1608Metric
C40: 22µF; C_0603_1608Metric
C41: 22µF; C_1206_3216Metric
C42: 100nF; C_1206_3216Metric
C43: 47uF; C_0603_1608Metric
C44: 10nF; C_0805_2012Metric
C47: 10uF; C_0603_1608Metric
C48: 47uF; C_0805_2012Metric
C49: 1nF; C_0805_2012Metric
D16: SMF12A; D_SMF
D17, D18, D19, D20: SS34; D_SMA
F2: 3A; Fuse_1812_4532Metric
IC1, IC2: MP1584EN-LF-Z; SOIC127P600X170-9N; MOUSER_PART_NUMBER 946-MP1584ENLFZ
J7: Barrel_Jack; BarrelJack_CUI_PJ-102AH_Horizontal
L2: 15µH; L_7.3x7.3_H4.5
L3: 6.8µH; L_7.3x7.3_H4.5
L4: 22µH; L_10.4x10.4_H4.8
R41: 100k; R_0603_1608Metric
R42: 68k; R_0603_1608Metric
R43, R44: 193k; R_0603_1608Metric
R45, R46: 40,2k; R_0603_1608Metric
R47: 211k; R_0603_1608Metric
R48: 124k; R_0603_1608Metric
R49: 140k; R_0603_1608Metric
R50, R51: 10K; R_0603_1608Metric
U12: TPS54331DG4; SOIC127P599X175-8N

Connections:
12V_SYSTEM: C32.1, C34.1, C43.1, IC1.2 (EN), IC1.7 (VIN), IC2.2 (EN), IC2.7 (VIN), L4.2, R49.1; also elsewhere on the board
19V: C46.2, F2.1, U12.2 (VIN), U12.3 (EN); also elsewhere on the board
+3V3: C41.1, L3.2, R48.2; also elsewhere on the board
+5V: C40.1, L2.2, R47.2; also elsewhere on the board
GND: C33.2, C35.2, C36.2, C37.2, C40.2, C41.2, C42.2, C44.2, C48.1, C49.2, D16.2 (A2), D17.2 (A), D18.2 (A), D19.2 (A), D20.2 (A), IC1.5 (GND), IC1.9 (EP), IC2.5 (GND), IC2.9 (EP), J7.2, R43.2, R44.2, R45.1, R46.1, R50.2, U12.7 (GND); also elsewhere on the board
unnamed: C32.2, C33.1
unnamed: C34.2, C35.1
unnamed: C36.1, R41.2
unnamed: C37.1, R42.2
unnamed: C42.1, C43.2
unnamed: C46.1, C47.2
unnamed: C47.1, C48.2
unnamed: C49.1, R51.2
unnamed: D16.1 (A1), D17.1 (K), F2.2, J7.1
unnamed: C38.2, D18.1 (K), IC1.1 (SW), L2.1
unnamed: C39.2, D19.1 (K), IC2.1 (SW), L3.1
unnamed: C45.1, D20.1 (K), L4.1, U12.8 (PH)
unnamed: C38.1, IC1.8 (BST)
unnamed: IC1.3 (COMP), R41.1
unnamed: IC1.4 (FB), R45.2, R47.1
unnamed: IC1.6 (FREQ), R43.1
unnamed: C39.1, IC2.8 (BST)
unnamed: IC2.3 (COMP), R42.1
unnamed: IC2.4 (FB), R46.2, R48.1
unnamed: IC2.6 (FREQ), R44.1
unnamed: C45.2, U12.1 (BOOT)
unnamed: R51.1, U12.6 (COMP)
unnamed: C44.1, U12.4 (SS)
unnamed: R49.2, R50.1, U12.5 (VSENSE)

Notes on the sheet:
12V
19V
3V3

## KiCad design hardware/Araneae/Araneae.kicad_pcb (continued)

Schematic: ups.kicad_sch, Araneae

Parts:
BT1, BT2: 1048; BAT_1048; PARTREV A
C1, C2, C3, C5, C6, C7, C12, C14, C18, C85, C86, C87: 100nF; C_0603_1608Metric
C4: 10nF; C_0603_1608Metric
C8, C16, C17: 10µF; C_0805_2012Metric
C9: 0.1µF; C_0603_1608Metric
C10: 4.7µF; C_0805_2012Metric
C11, C15: 1µF; C_0603_1608Metric
C13: 2.2µF; C_0603_1608Metric
D1: MBRS340; D_SMC
D2: LED; LED_0805_2012Metric
L1: 22µH; L_10.4x10.4_H4.8
Q1, Q3: PMOS; SOT-23
Q2, Q4: NMOS; SOT-23
R1, R16: 10mΩ; R_2512_6332Metric
R2, R3, R5, R11, R15, R17, R21, R23: 10k; R_0603_1608Metric
R4, R9, R10, R12, R14: 100k; R_0603_1608Metric
R6: 100Ω; R_0805_2012Metric
R7, R8: 4.7Ω; R_0603_1608Metric
R18: 301k; R_0603_1608Metric
R20: 124k; R_0603_1608Metric
R22: 95.3k; R_0603_1608Metric
R24: 30mΩ; R_2512_6332Metric
R120, R121: 4.7k; R_0603_1608Metric
TH1, TH2: 10k; R_0603_1608Metric
U1: LTC4412xS6; TSOT-23-6
U2: ISL94202IRTZ; QFN40P600X600X80-49N; PARTREV 3.00
U3, U4: IRLR7843; TO252
U5: LTC4015EUHF; QFN50P700X500X80-39N

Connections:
12V_SYSTEM: C85.1, U1.1 (VIN), U5.31 (SYS); also elsewhere on the board
19V: C17.1, Q3.3 (S), Q4.1 (D), R15.1, R16.1, R16.2, R20.2, U5.32 (CLN), U5.33 (CLP), U5.35 (VIN); also elsewhere on the board
+3V3: C6.2, R5.2, R17.2, U1.3 (CTL); also elsewhere on the board
+12V: D1.1 (K), Q1.1 (D), Q1.3 (S), R1.1, U1.6 (SENSE), U2.1 (VC8), U2.3 (VC7), U2.5 (VC6), U2.7 (VC5), U2.9 (VC4), U2.47 (CSI1), U2.48 (VBATT); also elsewhere on the board
/UPS Subsystem/2P5VCC: C11.1, C13.1, U5.22 (2P5VCC)
/UPS Subsystem/+12V_BAT: BT2.P2, D1.2 (A), R1.2, U2.10 (CB4), U2.46 (CSI2)
/UPS Subsystem/BAT_P: R24.2, U5.18 (BATSENS), U5.19 (CSN)
/UPS Subsystem/BG: Q2.2 (G), U5.26 (BG)
/UPS Subsystem/CCREFM: C7.2, R18.1, U5.16 (CCREFM)
/UPS Subsystem/CCREFP: C7.1, R18.2, U5.17 (CCREFP)
/UPS Subsystem/CSP: C86.2, L1.1, R24.1, U5.20 (CSP)
/UPS Subsystem/DVCC: C8.1, C10.1, C16.1, U5.3 (DVCC), U5.4 (SCL), U5.5 (SDA), U5.28 (INTVCC), U5.36 (CHEM0)
/UPS Subsystem/SW: C12.2, L1.2, Q2.1 (D), Q4.3 (S), U5.23 (SW)
/UPS Subsystem/TG: Q4.2 (G), U5.24 (TG)
/UPS Subsystem/UPS1_N1: BT1.N1, BT1.P2, U2.14 (CB2)
/UPS Subsystem/UPS1_N2: BT1.N2, BT1.P1, U2.15 (VC1), U2.16 (CB1)
/UPS Subsystem/UPS2_N2: BT2.N2, BT2.P1, U2.11 (VC3), U2.12 (CB3), U2.13 (VC2)
EXT_I2C_SCL: R120.2, U2.25 (SCL); also elsewhere on the board
EXT_I2C_SDA: R121.2, U2.26 (SDAI), U2.27 (SDAO); also elsewhere on the board
GND: BT2.N1, C1.2, C2.1, C3.2, C4.2, C5.1, C9.2, C10.2, C11.2, C13.2, C14.2, C15.2, C16.2, C18.2, C87.2, Q2.3 (S), R2.2, R3.2, R4.1, R8.1, R9.2, R15.2, R22.2, TH2.2, U1.2 (GND), U2.17 (VC0), U2.18 (VSS), U2.24 (ADDR), U2.28 (VSS), U2.29 (VSS), U2.44 (PCFET), U2.49 (VSS), U3.2, U4.2, U5.1 (CELLS1), U5.2 (CELLS2), U5.7 (SGND), U5.13 (EQ), U5.14 (GND), U5.21 (MPPT), U5.37 (CHEM1), U5.39 (EXP); also elsewhere on the board
LTC4015_ALERT: R17.1, U5.6 (~SMBALERT); also elsewhere on the board
unnamed: C8.2, C9.1
unnamed: C14.1, R23.1
unnamed: C17.2, C18.1
unnamed: D2.2 (A), U1.4 (STAT)
unnamed: D2.1 (K), R5.1
unnamed: Q1.2 (G), U1.5 (GATE)
unnamed: Q3.1 (D), U5.34 (INFET)
unnamed: Q3.2 (G), U5.29 (OUTFET)
unnamed: R6.2, R8.2, U4.1
unnamed: R7.1, U3.1
unnamed: C1.1, U2.41 (C1)
unnamed: C2.2, U2.40 (C2)
unnamed: C3.1, U2.39 (C3)
unnamed: R6.1, U2.45 (CFET)
unnamed: R2.1, U2.37 (CHMON)
unnamed: R7.2, U2.42 (DFET)
unnamed: R4.2, U2.33 (FETSOFF)
unnamed: R3.1, U2.38 (LDMON)
unnamed: R14.2, U2.32 (PSD)
unnamed 243: C87.1, R10.1, R11.1, R12.1, R14.1, R120.1, R121.1, U2.36 (RGO); also elsewhere on the board
unnamed: C4.1, R9.1, U2.22 (TEMPO)
unnamed: C6.1, U2.43 (VDD)
unnamed: C5.2, U2.19 (VREF)
unnamed: TH1.2, U2.20 (XT1)
unnamed: TH1.1, U2.21 (XT2)
unnamed: R10.2, U2.35 (~EOC)
unnamed: R11.2, U2.31 (~INT)
unnamed: R12.2, U2.34 (~SD)
unnamed: U3.3, U4.3
unnamed: C12.1, U5.25 (BOOST)
unnamed: C86.1, U5.15 (CSPM5)
unnamed: C15.1, U5.27 (DRVCC)
unnamed: R21.1, TH2.1, U5.11 (NTC)
unnamed: R21.2, U5.12 (NTCBIAS)
unnamed: R22.1, U5.10 (RT)
unnamed: C85.2, U5.30 (SYSM5)
unnamed: R20.1, U5.8 (UVCLFB)
unnamed: R23.2, U5.9 (VC)

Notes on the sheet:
Official Quality Certified LFP 26650 3.2v 2500Mh Grade A_P LiFePO4 Battery Rechargeable Battery Golfcarts RV Deep Cycle Battery
1.2 × (124k + 10k) / 10k ≈ 16.1V
3.2v x 4 = 12,8v

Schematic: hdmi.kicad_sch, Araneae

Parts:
F1: 500mA; Fuse_1206_3216Metric
J3: HDMI_A; HDMI_A_Molex_208658-1001_Horizontal

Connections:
+5V: F1.2; also elsewhere on the board
/CM4/HDMI0_CEC: J3.13 (CEC); also elsewhere on the board
/CM4/HDMI0_CLK_N: J3.12 (CK_N); also elsewhere on the board
/CM4/HDMI0_CLK_P: J3.10 (CK_P); also elsewhere on the board
/CM4/HDMI0_HPD: J3.19 (HPD); also elsewhere on the board
/CM4/HDMI0_SCL: J3.15 (SCL); also elsewhere on the board
/CM4/HDMI0_SDA: J3.16 (SDA); also elsewhere on the board
/CM4/HDMI0_TX0_N: J3.9 (D0_N); also elsewhere on the board
/CM4/HDMI0_TX0_P: J3.7 (D0_P); also elsewhere on the board
/CM4/HDMI0_TX1_N: J3.6 (D1_N); also elsewhere on the board
/CM4/HDMI0_TX1_P: J3.4 (D1_P); also elsewhere on the board
/CM4/HDMI0_TX2_N: J3.3 (D2_N); also elsewhere on the board
/CM4/HDMI0_TX2_P: J3.1 (D2_P); also elsewhere on the board
GND: J3.2 (D2S), J3.5 (D1S), J3.8 (D0S), J3.11 (CKS), J3.17 (GND), J3.SH; also elsewhere on the board
unnamed: F1.1, J3.18 (+5V)

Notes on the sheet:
CM4 Datasheet doesn't needs TVS for HDMI

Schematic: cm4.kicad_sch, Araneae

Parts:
R25: 220Ω; R_0805_2012Metric
X1, X2: DF40HC_3.0_-100DS-0.4V_58; HRS_DF40HC_3.0_-100DS-0.4V_58

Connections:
+1V8: X1.88, X1.90, X1.94, X1.96; also elsewhere on the board
+3V3: X1.78, X1.84, X1.86; also elsewhere on the board
+5V: X1.77, X1.79, X1.81, X1.83, X1.85, X1.87; also elsewhere on the board
/CM4/CD1_SCL: X1.80; also elsewhere on the board
/CM4/CD1_SDA: X1.82; also elsewhere on the board
/CM4/CM4_USB_D_N: X2.3; also elsewhere on the board
/CM4/CM4_USB_D_P: X2.5; also elsewhere on the board
/CM4/DSI1_CLK_N: X2.87; also elsewhere on the board
/CM4/DSI1_CLK_P: X2.89; also elsewhere on the board
/CM4/DSI1_D0_N: X2.75; also elsewhere on the board
/CM4/DSI1_D0_P: X2.77; also elsewhere on the board
/CM4/DSI1_D1_N: X2.81; also elsewhere on the board
/CM4/DSI1_D1_P: X2.83; also elsewhere on the board
/CM4/DSI1_D2_N: X2.93; also elsewhere on the board
/CM4/DSI1_D2_P: X2.95; also elsewhere on the board
/CM4/DSI1_D3_N: X2.94; also elsewhere on the board
/CM4/DSI1_D3_P: X2.96; also elsewhere on the board
/CM4/ETH1_LED1: X1.15; also elsewhere on the board
/CM4/ETH1_LED2: X1.17; also elsewhere on the board
/CM4/ETH1_MX1_N: X1.10; also elsewhere on the board
/CM4/ETH1_MX1_P: X1.12; also elsewhere on the board
/CM4/ETH1_MX2_N: X1.6; also elsewhere on the board
/CM4/ETH1_MX2_P: X1.4; also elsewhere on the board
/CM4/ETH1_MX3_N: X1.9; also elsewhere on the board
/CM4/ETH1_MX3_P: X1.11; also elsewhere on the board
/CM4/ETH1_MX4_N: X1.5; also elsewhere on the board
/CM4/ETH1_MX4_P: X1.3; also elsewhere on the board
/CM4/ETH_INTRP_N: X1.41; also elsewhere on the board
/CM4/ETH_SCS_N: X1.45; also elsewhere on the board
/CM4/HDMI0_CEC: X2.51; also elsewhere on the board
/CM4/HDMI0_CLK_N: X2.90; also elsewhere on the board
/CM4/HDMI0_CLK_P: X2.88; also elsewhere on the board
/CM4/HDMI0_HPD: X2.53; also elsewhere on the board
/CM4/HDMI0_SCL: X2.100; also elsewhere on the board
/CM4/HDMI0_SDA: X2.99; also elsewhere on the board
/CM4/HDMI0_TX0_N: X2.84; also elsewhere on the board
/CM4/HDMI0_TX0_P: X2.82; also elsewhere on the board
/CM4/HDMI0_TX1_N: X2.78; also elsewhere on the board
/CM4/HDMI0_TX1_P: X2.76; also elsewhere on the board
/CM4/HDMI0_TX2_N: X2.72; also elsewhere on the board
/CM4/HDMI0_TX2_P: X2.70; also elsewhere on the board
/CM4/SD_CLK: X1.57; also elsewhere on the board
/CM4/SD_DAT0: X1.63; also elsewhere on the board
/CM4/SD_DAT1: X1.67; also elsewhere on the board
/CM4/SD_DAT2: X1.69; also elsewhere on the board
/CM4/SD_DAT3: X1.61; also elsewhere on the board
/CM4/SD_PWR: X1.62; also elsewhere on the board
/CM4/SD_PWR_ON: X1.75; also elsewhere on the board
/CM4/SSD_3V3_EN: X2.11
/CM4/SSD_CLKREQ_IN: X2.2
/CM4/SSD_PERST_IN: X2.9
/CM4/SSD_PERn0: X2.18; also elsewhere on the board
/CM4/SSD_PERp0: X2.16; also elsewhere on the board
/CM4/SSD_PETn0: X2.24; also elsewhere on the board
/CM4/SSD_PETp0: X2.22; also elsewhere on the board
/CM4/SSD_REFCLKn: X2.12; also elsewhere on the board
/CM4/SSD_REFCLKp: X2.10; also elsewhere on the board
/CM4/USB_HUB_RESET_N: X1.100; also elsewhere on the board
/CM4/WATCHDOG_WDI: X1.46; also elsewhere on the board
Bottom_Fan_PWM: X1.28; also elsewhere on the board
Bottom_Fan_Sense: X1.50; also elsewhere on the board
EXT_GPIO1: X1.27; also elsewhere on the board
EXT_GPIO2: X1.25; also elsewhere on the board
EXT_GPIO3: X1.24; also elsewhere on the board
EXT_GPIO4: X1.30; also elsewhere on the board
EXT_GPIO5: X1.48; also elsewhere on the board
EXT_GPIO6: X2.19; also elsewhere on the board
EXT_GPIO7: X2.31; also elsewhere on the board
EXT_GPIO8: X2.25; also elsewhere on the board
EXT_GPIO9: X2.23; also elsewhere on the board
EXT_GPIO10: X2.37; also elsewhere on the board
EXT_I2C_SCL: X1.56; also elsewhere on the board
EXT_I2C_SDA: X1.58; also elsewhere on the board
EXT_PWM0: X1.49; also elsewhere on the board
EXT_PWM1: X1.26; also elsewhere on the board
EXT_SPI_CS0: X1.39; also elsewhere on the board
EXT_SPI_CS1: X1.37; also elsewhere on the board
EXT_SPI_MISO: X1.40; also elsewhere on the board
EXT_SPI_MOSI: X1.44; also elsewhere on the board
EXT_SPI_SCLK: X1.38; also elsewhere on the board
EXT_UART_RX: X1.34; also elsewhere on the board
EXT_UART_TX: X1.54; also elsewhere on the board
GND: X1.1, X1.2, X1.7, X1.8, X1.13, X1.14, X1.22, X1.23, X1.32, X1.33, X1.42, X1.43, X1.52, X1.53, X1.59, X1.60, X1.65, X1.66, X1.71, X1.74, X1.98, X2.1, X2.7, X2.8, X2.13, X2.14, X2.20, X2.26, X2.32, X2.38, X2.44, X2.50, X2.55, X2.56, X2.61, X2.62, X2.67, X2.68, X2.73, X2.74, X2.79, X2.80, X2.85, X2.86, X2.91, X2.92, X2.97, X2.98; also elsewhere on the board
LTC4015_ALERT: X1.47; also elsewhere on the board
unnamed: R25.1, X1.92
RESET_GLOBAL: R25.2; also elsewhere on the board
RX_DEBUG: X1.51; also elsewhere on the board
SCL_DEBUG: X1.35; also elsewhere on the board
SDA_DEBUG: X1.36; also elsewhere on the board
TX_DEBUG: X1.55; also elsewhere on the board
Top_Fan_PWM: X1.31; also elsewhere on the board
Top_Fan_Sense: X1.29; also elsewhere on the board

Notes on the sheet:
CM4 Lite w/ WiFi

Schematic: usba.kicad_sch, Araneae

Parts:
C30, C31: 100nF; C_0603_1608Metric
D8, D9, D10, D11, D12, D13: ESD_USB; D_SOD-323
J4: USB_A_Stacked; USB_A_CUI_UJ2-ADH-TH_Horizontal_Stacked
J5: USB_A; USB_A_Wuerth_614004134726_Horizontal
R37, R38: 1MΩ; R_0603_1608Metric
U8, U9, U10: TPS2041B; SOT-23-5

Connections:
+5V: U8.5 (IN), U9.5 (IN), U10.5 (IN); also elsewhere on the board
/USB Hub/USBA1_D_N: D9.2 (A2), J4.2 (D1_N); also elsewhere on the board
/USB Hub/USBA1_D_P: D8.2 (A2), J4.3 (D1_P); also elsewhere on the board
/USB Hub/USBA1_FAULT_N: U10.3 (~OC); also elsewhere on the board
/USB Hub/USBA1_PWR_EN: U10.4 (~EN); also elsewhere on the board
/USB Hub/USBA2_D_N: D10.2 (A2), J4.7 (D2_P); also elsewhere on the board
/USB Hub/USBA2_D_P: D11.2 (A2), J4.6 (D2_N); also elsewhere on the board
/USB Hub/USBA2_FAULT_N: U8.3 (~OC); also elsewhere on the board
/USB Hub/USBA2_PWR_EN: U8.4 (~EN); also elsewhere on the board
/USB Hub/USBA3_D_N: D12.2 (A2), J5.2 (D_N); also elsewhere on the board
/USB Hub/USBA3_D_P: D13.2 (A2), J5.3 (D_P); also elsewhere on the board
/USB Hub/USBA3_FAULT_N: U9.3 (~OC); also elsewhere on the board
/USB Hub/USBA3_PWR_EN: U9.4 (~EN); also elsewhere on the board
GND: C30.2, C31.2, D8.1 (A1), D9.1 (A1), D10.1 (A1), D11.1 (A1), D12.1 (A1), D13.1 (A1), J4.4 (GND1), J4.8 (GND2), J5.4 (GND), U8.2 (GND), U9.2 (GND), U10.2 (GND); also elsewhere on the board
unnamed: C30.1, R37.1
unnamed: C31.1, R38.2
unnamed: J4.9 (Shield), R37.2
unnamed: J4.1 (VBUS1), U9.1 (OUT)
unnamed: J4.5 (VBUS2), U8.1 (OUT)
unnamed: J5.5 (Shield), R38.1
unnamed: J5.1 (VBUS), U10.1 (OUT)

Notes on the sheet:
USB ports operate at USB 2.0 speeds due to CM4 limitations. High-speed storage is provided via PCIe.

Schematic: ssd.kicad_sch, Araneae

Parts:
C19: 100nF; C_0603_1608Metric
D3: LED; LED_0805_2012Metric
J1: MDT320M01001; AMPHENOL_MDT320M01001; PARTREV 7
R26: 1k; R_0603_1608Metric
R27: 10k; R_0603_1608Metric
R28: 100k; R_0603_1608Metric
R29: 33R; R_0603_1608Metric
Y1: 32.768kHz; Oscillator_SMD_Abracon_ASCO-4Pin_1.6x1.2mm

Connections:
3V3_SSD: C19.1, J1.2, J1.4, J1.12, J1.14, J1.16, J1.18, J1.70, J1.72, J1.74, R26.1, R27.2, R28.2, Y1.4 (VDD); also elsewhere on the board
/CM4/SSD_PERn0: J1.47; also elsewhere on the board
/CM4/SSD_PERp0: J1.49; also elsewhere on the board
/CM4/SSD_PETn0: J1.41; also elsewhere on the board
/CM4/SSD_PETp0: J1.43; also elsewhere on the board
/CM4/SSD_PEWAKE#: J1.54, R27.1
/CM4/SSD_REFCLKn: J1.53; also elsewhere on the board
/CM4/SSD_REFCLKp: J1.55; also elsewhere on the board
/CM4/SSD_SUSCLK: J1.68, R29.2
/SSD PCle/SSD_CLKREQ#: J1.52; also elsewhere on the board
/SSD PCle/SSD_PERST#: J1.50; also elsewhere on the board
GND: C19.2, J1.1, J1.3, J1.9, J1.15, J1.21, J1.27, J1.33, J1.39, J1.45, J1.51, J1.57, J1.71, J1.73, J1.75, Y1.2 (GND); also elsewhere on the board
unnamed: D3.2 (A), R26.2
unnamed: D3.1 (K), J1.10
unnamed: R29.1, Y1.3 (OUT)
unnamed: R28.1, Y1.1 (Tri-State)

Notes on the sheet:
SSD PCIe

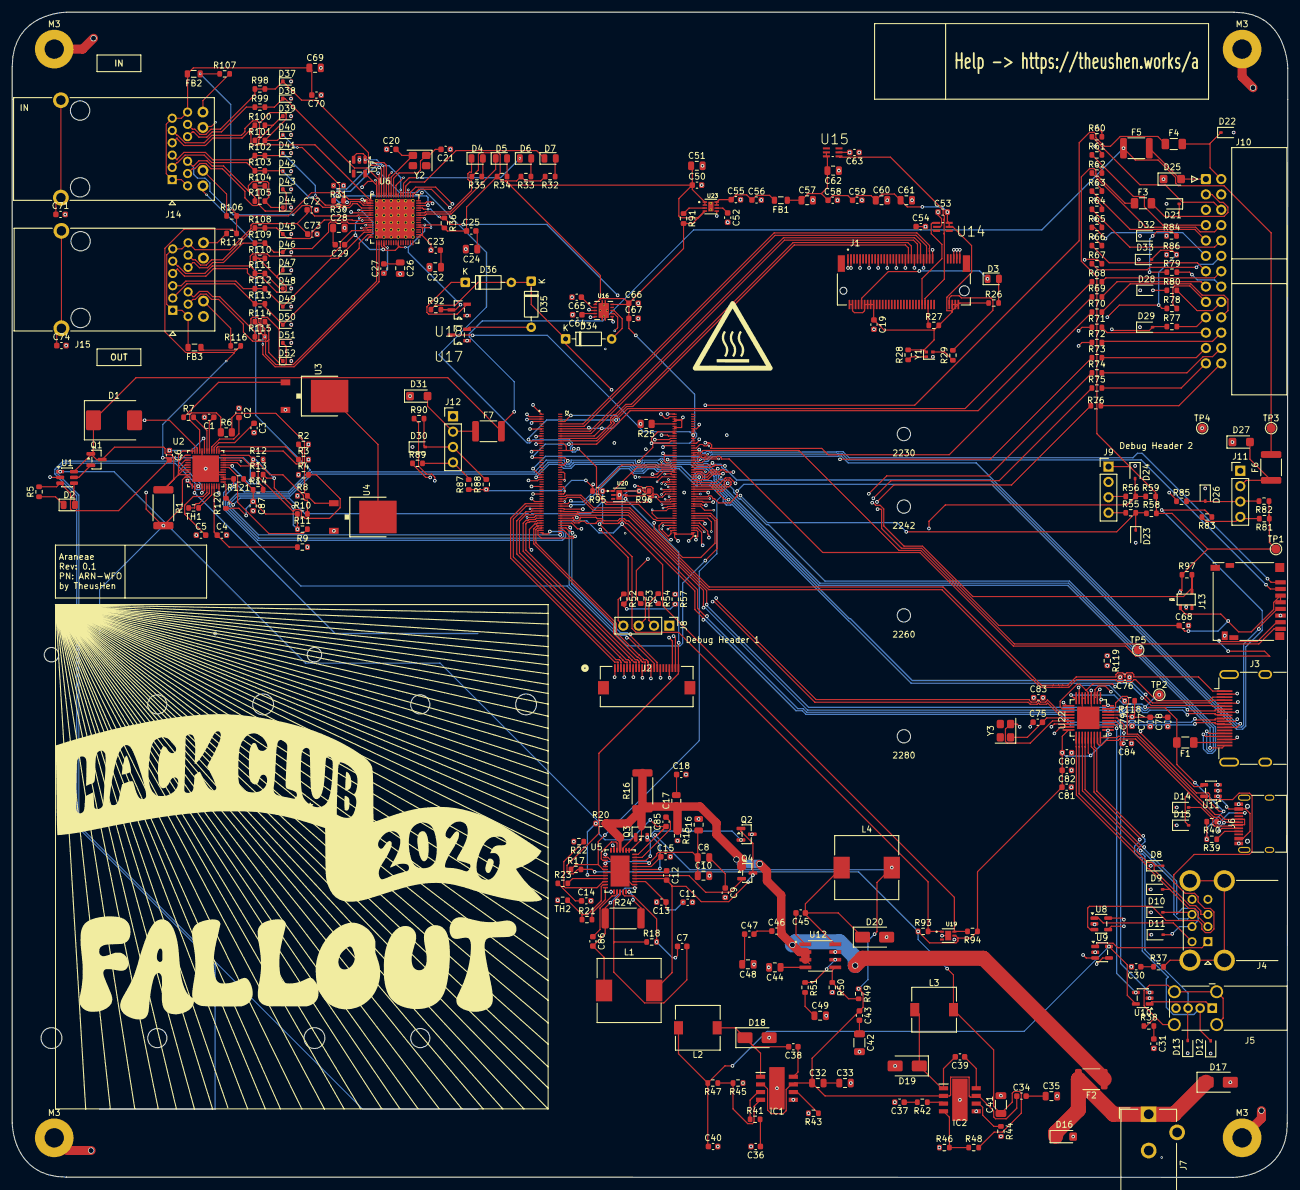
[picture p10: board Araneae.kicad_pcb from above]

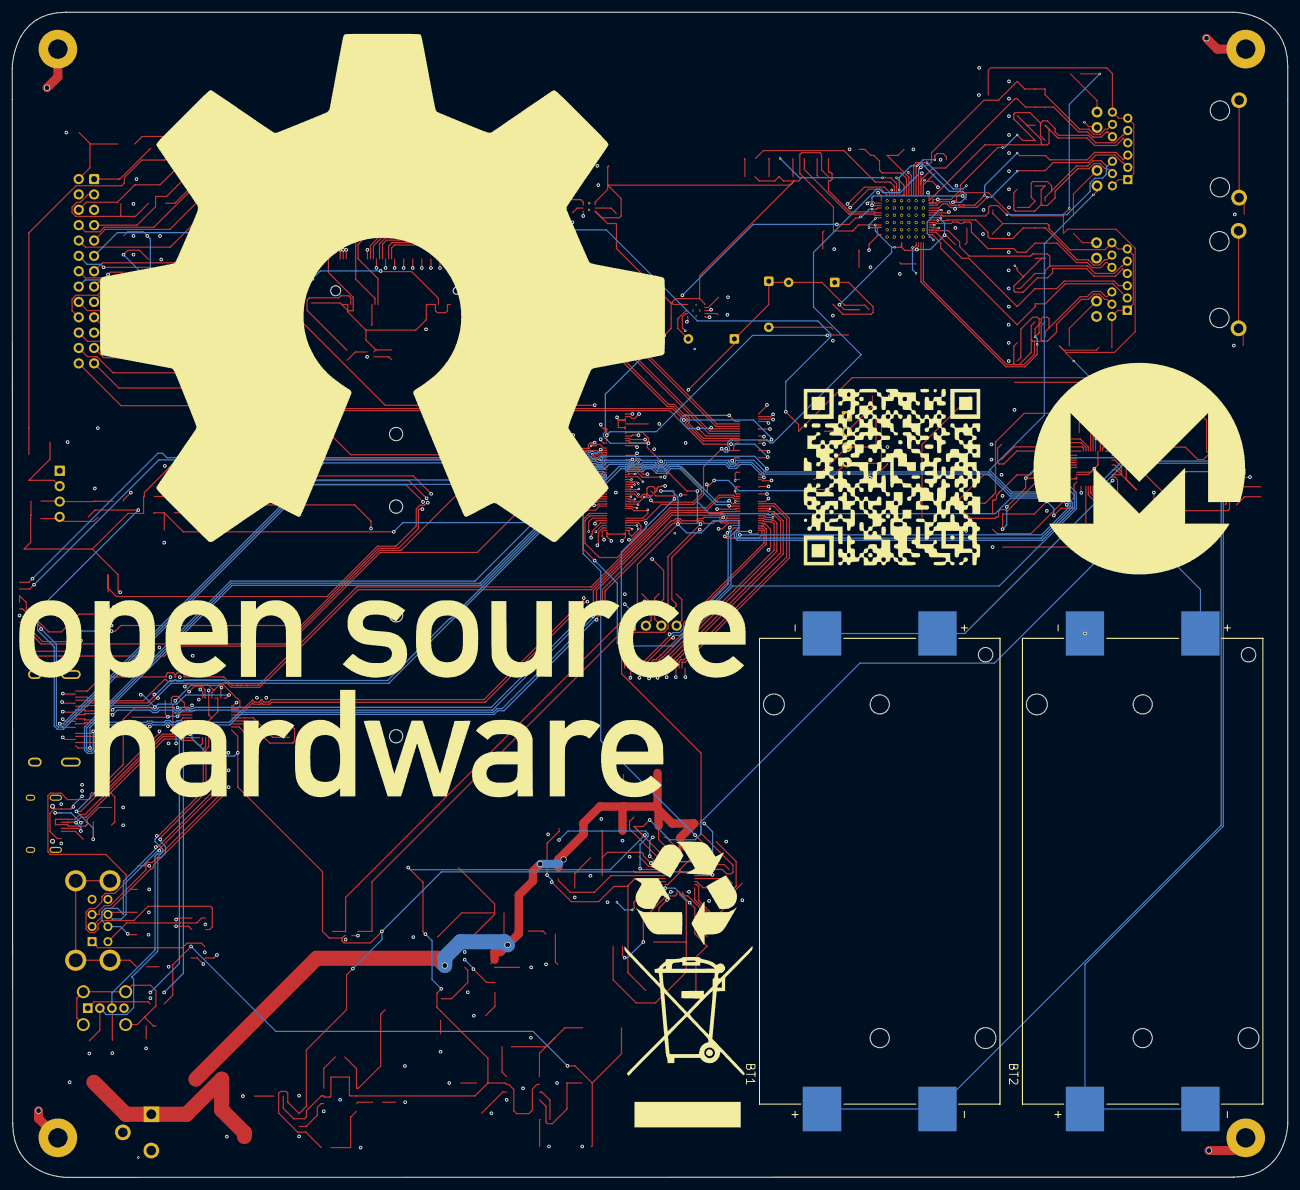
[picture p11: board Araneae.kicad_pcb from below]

Board: 6 copper layers, 211.0 x 192.7 mm, 338 parts (2 on the bottom side), 284 nets.

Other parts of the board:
2230, 2242, 2260, 2280: MountingHole_2.2mm_M2
M3, M3#2, M3#3, M3#4: MountingHole_3.2mm_M3_Pad
R13: 10k; R_0603_1608Metric

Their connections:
+3V3: R13.1; also elsewhere on the board
GND: M3.1, M3#2.1, M3#3.1, M3#4.1; also elsewhere on the board
unnamed 243: R13.2; also elsewhere on the board

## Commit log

2026-04-12 chore(hardware): add KiCad project, Git LFS for CAD outputs, extend gitignore
    [1048.step, Araneae.kicad_pcb, Araneae.kicad_sch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]
2026-05-09 Add CI workflow for PCB checks and artifact generation
    - Created a GitHub Actions workflow (`ci.yml`) to automate hardware checks including ERC, DRC, and plot generation for KiCad projects.
    - Added a new footprint for the SON50P200X200X80-9N component in `SON50P200X200X80-9N.kicad_mod`.
    - Introduced a new symbol for the TPS22965DSGR component in `TPS22965DSGR.kicad_sym`.
    - Added a configuration file `kibot.yaml` for generating fabrication files and other outputs.
    [Araneae.kicad_pcb, Araneae.kicad_sch, cm4.kicad_sch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]
2026-05-09 refactor: update CI workflow for KiCad checks and improve README formatting
2026-05-09 feat: add PCB_SVG_LAYERS environment variable and update SVG export command
2026-05-09 fix: rename PCB_SVG_LAYERS to PCB_PLOT_LAYERS and update export commands for KiCad
2026-05-09 feat: update fabrication file generation to use KiCad CLI and add support for gerbers, drill files, and BOM export
2026-05-18 Add Araneae OS OpenWrt starter kit
    Introduce an OpenWrt Image Builder scaffold for the Raspberry Pi CM4/RPi4 target, including package lists, first-boot provisioning, WireGuard, storage, Docker, and Mattermost defaults.
    Add documentation and release automation so Araneae OS images can be built reproducibly from changes under araneae-os/.
2026-05-18 Fix Araneae OS image rootfs sizing
    Pass ROOTFS_PARTSIZE from the OpenWrt profile so the Raspberry Pi image has enough space for LuCI, Docker, storage packages, and Mattermost support.
    Enable verbose Image Builder logs through the profile to make future CI failures easier to diagnose.
2026-05-18 Fix OpenWrt package selection
    Replace unavailable WireGuard LuCI package with luci-proto-wireguard and drop packages that are not present for OpenWrt 24.10.6 on bcm27xx/bcm2711.
    Remove the default dnsmasq package when installing dnsmasq-full to avoid Image Builder file clashes.

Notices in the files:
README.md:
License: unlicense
